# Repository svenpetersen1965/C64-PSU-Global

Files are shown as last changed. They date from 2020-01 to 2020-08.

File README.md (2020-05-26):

# C64-PSU-Global
A replacement PSU for the Commodore C64, which works with 230V/115V.

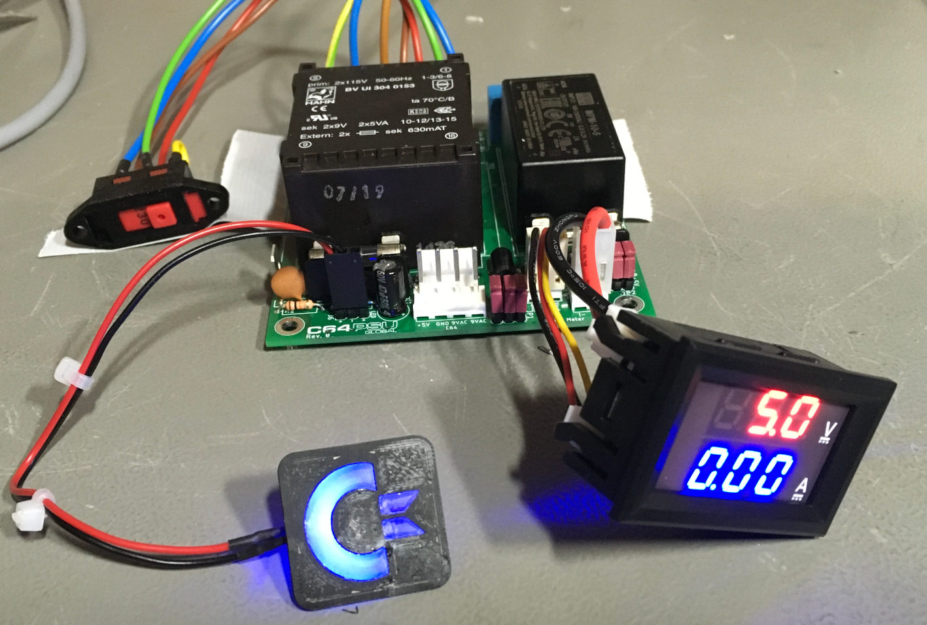
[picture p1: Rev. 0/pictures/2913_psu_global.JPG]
C64 PSU Global (PCB only)
 
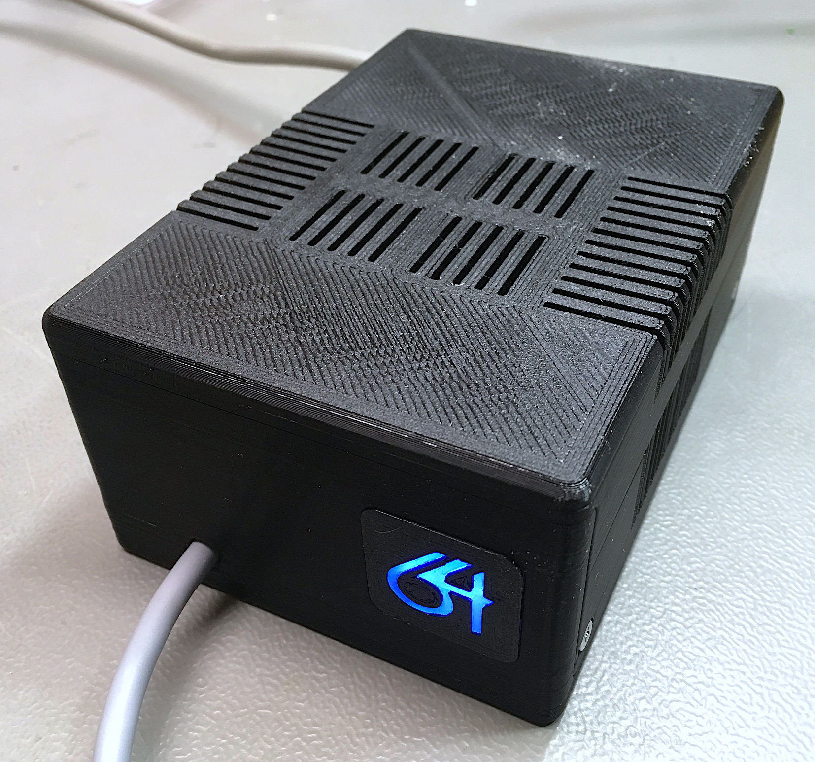
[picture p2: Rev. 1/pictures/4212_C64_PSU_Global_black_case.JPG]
C64 PSU Global (PCB only)


For using this PSU, a suitable enclosure is required. It must not be connected to 230V while 115V mains is selected.

This PSU is designed for a low price at a decent comfort and for providing a PSU that can be switched between 230V and 115V mains.

The testing of Rev. 0 is still preliminary. The PSU was successfully tested with all ASSYs, that I have (250407, 250425, 250466, 250469). The panel meter current measurement worked, but the reading of all panelmeters was off, because those seem to have a bad quality. In Rev. 1 (yet to be released), the current measurement was dropped. The jumpers for bridging the current measurement should be replaced with short wire bridges in Rev. 0.

The changes in <b>Rev. 1</b> are the dropped current measurement. The freed space was used for wider copper tracks. The complete documentation, test documents are released now. The documentation of Rev. 0 will stay incomplete, most of the Rev. 1 documentation applies to Rev. 0 as well.  

Find some info on the required cable making <a href="http://tech.guitarsite.de/cable_making.html">on my website</a>

# Case
The case is designed. At 24°C room temperature the temperature measured above the transformer reached 44°C while powering an ASSY 250425 C64. This is not critical, since the critical temperature for PLA is 55°C-60°C. In case you need to operate the power supply in higher ambient temperatures, you should consider PETG or ABS for printing or install the PSU in a metal case.

The case was designed to fit the <a href="https://github.com/svenpetersen1965/Illuminated-Commmodore-logo">illuminated Commodore Logo</a> or <a href="https://github.com/svenpetersen1965/Illuminated-64-logo">64 Logo</a> (in my repository).  

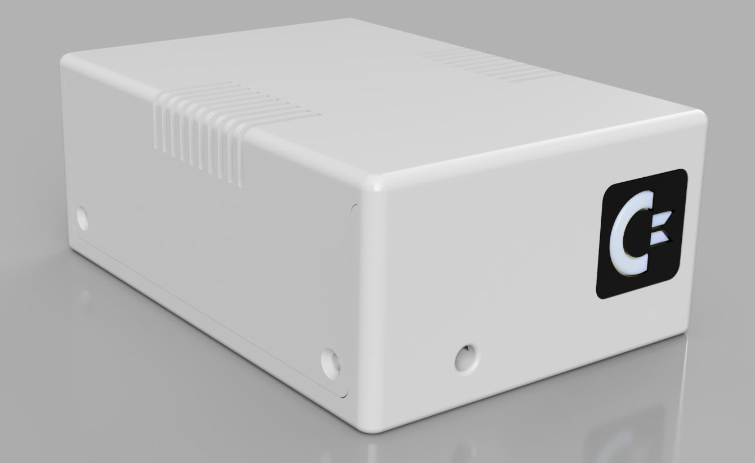
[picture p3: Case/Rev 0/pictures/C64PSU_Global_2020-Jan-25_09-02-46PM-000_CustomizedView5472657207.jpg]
C64 PSU Global case


Since there is a version of the PSU for 230V only and one version that can be switched between 115V and 230V, which requires a mains voltage selector switch, there are two versions for the bottom shell.

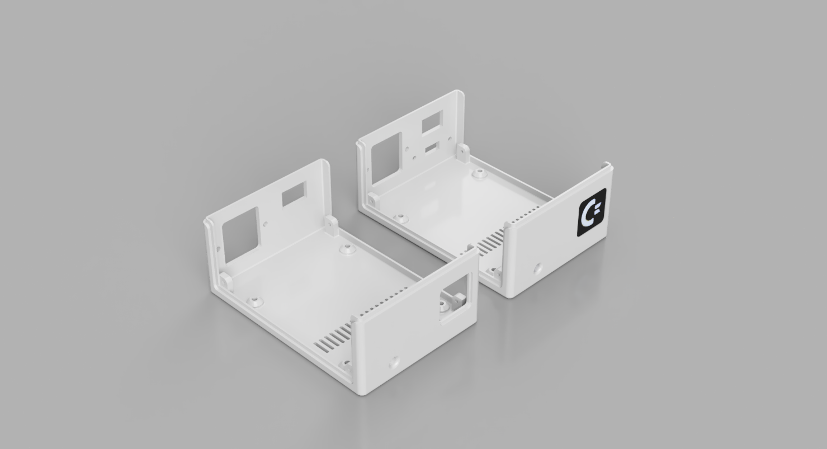
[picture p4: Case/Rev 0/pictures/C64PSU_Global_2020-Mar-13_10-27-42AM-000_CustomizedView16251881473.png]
C64 PSU Global bottom shells


# Prices
I have calculated the prices of May 2020.
Those prices do not include shipping fees and might differ from distributor to distributor. The prices of the items are from reichelt.de and tme.eu.

A 115V/230V type is 40,90€

A 230V only type is 35,11€

This does not incluse the 3D printed case, which might weigh 150g and take 12h to print.

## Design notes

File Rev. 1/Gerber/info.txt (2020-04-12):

      
       Board: C64_PSU_global
       Rev.:  1
  
       Files:
       ======
  
       All Gerber files are generated in extended gerber format (RS274X)
       *.TOP        : Film top copper
       *.BOT        :  -"- bottom copper
       *.STC        :  -"- top soldermask 
       *.STS        :  -"- bottom soldermask
       *.PLC        :  -"- silk screen top
       *.PLS        :  -"- silk screen bottom
       *.DK         : Drills plated Through (Excellon)
       *.NDK        : Drills not plated Through (Excellon)
       *.OUT        : Board outline

       Board Size:
       ===========
       Length     :   90.0 mm
       Width      :   84.0 mm
       Thickness  :   1.6 mm
       Material   :   FR 4
       Copper     :   35 um
       Surface    :   HASL
       
       Remarks:
       ========
       Width >= 8mil
       Distance >= 6mil
       Drill >= 0.6mm

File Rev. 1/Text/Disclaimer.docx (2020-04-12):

Disclaimer

Working with mains voltages can be harmful and cause death. Do not connect this PCB to mains (230VAC) unless you are trained in doing so and know the required safety regulations.

This PSU is a prototype, it is not certified in any way and might only be used as a prototype under laboratory conditions. Usage is at own risk. Do not leave unattended while powered on.

The PSU is designed to be installed in a plastic case. In case a metal case is used, a 3 prong mains connector is required and the case has to be connected to PE in a suitable way.

The documentation is drafted to the best of my knowledge. The creator is not liable for the accuracy and completeness.

Disclaimer.docx 18.02.2020 17:17 Erstellt von Sven Petersen Seite 2 von 2 Dok.-Nr.: 000-8-00-00

Disclaimer.docx 18.02.2020 17:17 Drafted by Sven Petersen Page 1 of 1

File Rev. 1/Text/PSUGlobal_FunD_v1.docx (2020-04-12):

C64 PSU Global Rev. 1

Functional Description

J1 is the mains connector of the board. Up to 240V can be connected. Two types of transformers fit alternatively. TR2 is for 230V only, TR1 can be switched between 230V and 115V. In this case J2 has to be populated. The wiring and connections are shown in the schematics.

M1 and M2 are AC/DC modules, which provide +5V. Both modules can be populated alternatively. The criteria for choosing one of these is availability and price. The function is identical in this case.

F1 is the fuse for the 9VAC. D1 serves as an over-voltage protection.

F2 is the fuse for +5V. C1 and C2 are for smoothing the voltage, D2 is a minimal over-voltage protection. It is equivalent to the TVS diodes, which are sometimes retrofitted in the C64.

JP1 is for connecting an external (and hopefully more precise) over-voltage protection (aka “Saver”). This saver is not yet developed. In case no saver is installed, JP1 should be bridged.

J4 is for connecting a panel volt-meter.

J6 is for connecting a power LED. The value of R1 is calculated for installing a blue LED. For a red or green LED, 330R or 390R are recommended. The illuminated logo already has limiting resistors on board. In case this logo is used as a power indicator, R1 needs to be 0Ω or can be bridged with a piece of wire.

PSUGlobal_FunD_v1.docx 18.02.2020 17:22 Drafted by Sven Petersen Page 2 of 2 Doc.-No.: 133-6-02-01

PSUGlobal_FunD_v1.docx 18.02.2020 17:22 Drafted by Sven Petersen Page 1 of 1 Doc.-No.: 133-6-02-00

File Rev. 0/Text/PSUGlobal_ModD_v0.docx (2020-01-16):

C64 PSU Global Rev. 0

Module Description

# Introduction

The C64 PSU Global is a replacement power supply for the Commodore C64, which is suitable to power the Commodore computer from 115V and 230V.

There are two options for transformers for the 9VAC, one is capable of being switch between 115V and 230V.

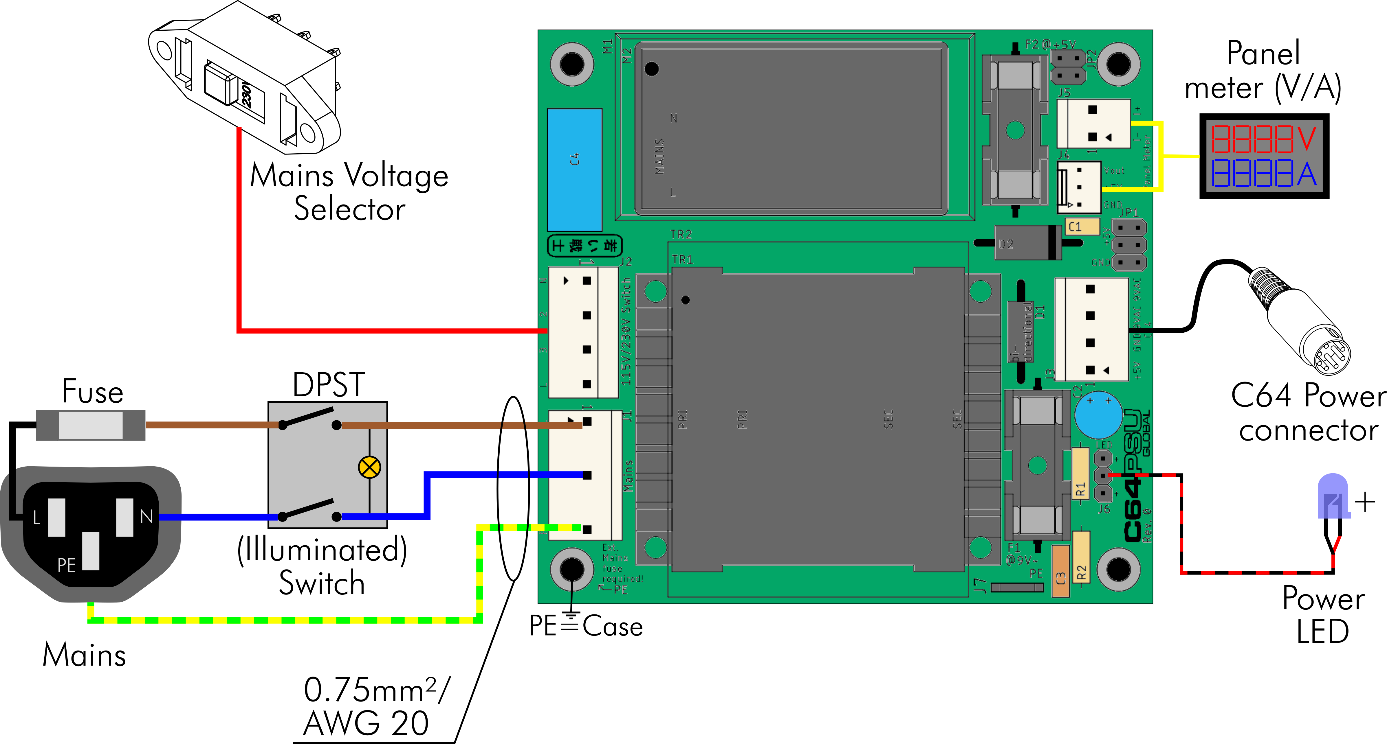
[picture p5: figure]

Figure 1: Block diagram

The 5VDC are generated by an AC/DC converter. There are two options that can be placed on the PCB, both have a wide range input (85VAC-264VAC) and are suitable for both main voltages without switching. The technical data of the power supply vary, depending on the chosen options:

Option | Type | Mains | Output
Transformer TR1 | Hahn BV UI 304 0153 | 115VAC/230VAC | 9VAC/1.1A
Transformer TR2 | BREVE TUFVASSONS TEZ10/D230/9V | 230VAC | 9VAC/1.1A
AC/DC M1 | RECOM RAC10-05SK/277 | 85VAC-305VAC | 5VDC/2A
AC/DC M2 | Mean Well MPM-10-5 | 80VAC-264VAC | 5VDC/2A

The mains voltage selector switch is only required for the option Transformer TR1. A fuse for the mains is external and mandatory. It is recommended to use a combination of mains with an integrated fuse and maybe a switch. The switch should switch off both, the hot and the neutral mains. In Figure 1, an illuminated mains switch is shown. Its lamp is located at the switched side.

A power LED can be connected. At least one signal should allow the use to notice, whether the PSU is switched on or off, the Power LED or the illuminated mains switch.

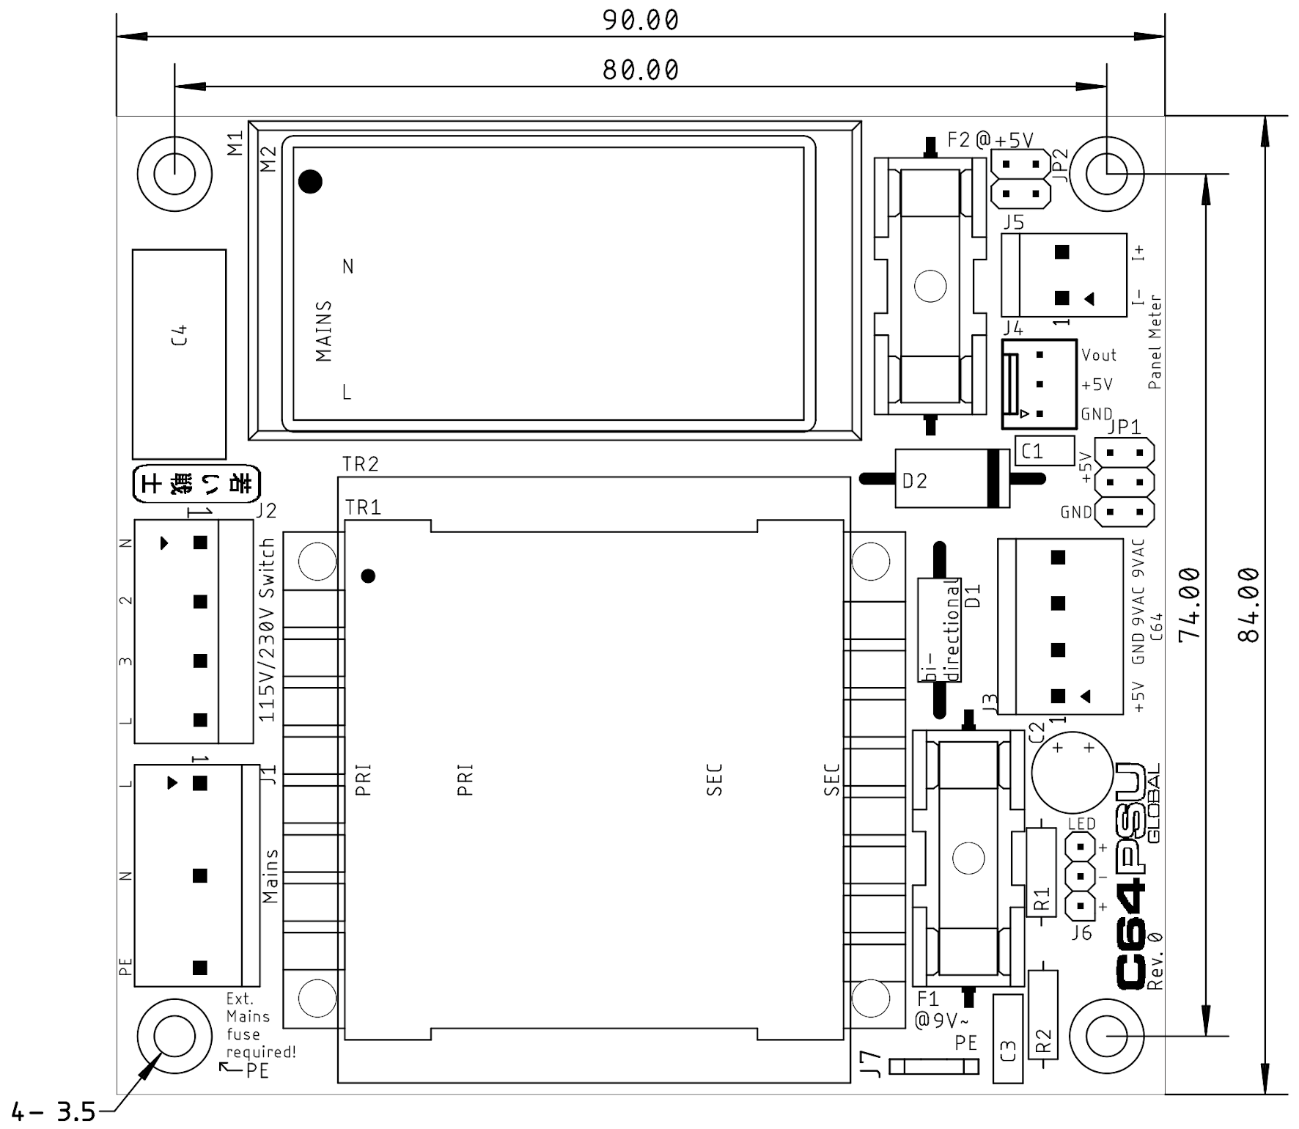
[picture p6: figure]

Figure 2: Dimensions

A panel meter can be connected. The common panel meter measures the current in the negative (ground) lead. The panel meters might be very inaccurate and the current and voltage should be adjusted with a load resistor and a multimeter. Sometimes, it is not even possible to adjust the current properly, so the panel meter is not really recommended. In case the panel meter is not installed, JP2 has to be bridged with jumpers.

A not yet developed over voltage protector (aka C64 saver) can be connected to JP1. In case this is not installed, JP1 has to be bridged with jumpers.

An R/C combination (R2/C3) between GND and PE serves for creating System Ground, which is tied to protective earth (PE). Some further power supplies for the monitor or the S-Video/HDMI converters might inject (a weak) mains voltage into the system. This happens due to a capacitive coupling to mains within those PSUs and could be felt when touching the C64 ports.

# Connectors

## J1 – Mains connectors

- Molex KK 396 Header, Vertical, Friction Lock, 5 Circuits, Tin (Sn) Plating (Pin 2 and pin 4 removed): P/N 0026604050
- KK 3.96mm Crimp Terminal Housing, Friction Ramp, 5 Circuits, Natural: P/N 09503051
- KK 396 Crimp Terminal 2478, 18-24 AWG, Bag, Brass Tin (Sn): P/N 08500106.

Pin | Signal
1 | L (hot)
3 | N (neutral)
5 | PE (protective earth)

## J2 – Mains Voltage Selector

This is an option and only required, if the TR1 (the 115V/230V type) is used.

- Molex 5.08mm Pitch SPOX Wire-to-Board Header, Vertical, with Friction Lock, 4 Circuits, P/N 10321041
- Molex 5.08mm Pitch SPOX Crimp Terminal Housing, 4 Circuits, P/N 10013046
- Molex SPOX Crimp Terminal, 18-24 AWG, Brass, P/N 08701031

As a switch, the type Bulgin T22205B436B is suggested.

## J3 – C64 Power Connector

- Molex KK 396 Header, Vertical, Friction Lock, 4 Circuits, Tin (Sn) Plating: P/N 0026604040
- KK 3.96mm Crimp Terminal Housing, Friction Ramp, 4 Circuits, Natural: P/N 09503041
- KK 396 Crimp Terminal 2478, 18-24 AWG, Bag, Brass Tin (Sn): P/N 08500106.

Pin | Signal
1 | +5V
2 | GND
3 | 9VAC2
4 | 9VAC1

## J4, J5 – Panel Meter

#### J5 – Current path

- Molex KK 396 Header, Vertical, Friction Lock, 2 Circuits, Tin (Sn) Plating: P/N 0026604020
- KK 3.96mm Crimp Terminal Housing, Friction Ramp, 2 Circuits, Natural: P/N 09503021
- KK 396 Crimp Terminal 2478, 18-24 AWG, Bag, Brass Tin (Sn): P/N 08500106.

Pin | Signal
1 | GND PSU (I-)
2 | GND OUT (I+)

### J4 – Voltage connection

- Molex KK 254 Wire-to-Board Header, Vertical, with Friction Lock, 3 Circuits, Tin (Sn) Plating: P/N 22272031
- KK 254 Crimp Housing, 3 Circuits, Natural: P/N 22-01-3037
- KK 254 Crimp Terminal, 22-30 AWG, Bag, Hot Tin (Sn) Dip Plating: P/N 08500114

Pin | Signal
1 | GND
2 | +5V (supply)
3 | +5V (measurement)

## Power LED – J6

- Pin header, 1x3 circuits, 2.54mm (0.1”) pitch
- Crimp housing: Dupont crimp housing
- Dupont crimp terminals

It is possible to use a widely available (Ebay, AliExpress etc.) Dupont cable, which can be cut and soldered to the LED.

Pin | Signal
1 | LED +
2 | LED -
3 | LED +

## J7 – PE Connection

The PE connection to the chassis is accomplished via the mounting hole marked with “← PE”. This is directly connected to the mains connector J1, Pin 5. In case other metal parts have to be grounded, a 6.3 x 0.8 FastOn (spade) connector can be installed in J7.

# Jumpers

## JP1 – Over-Voltage Protection

In case an over-voltage protection is not installed, the pin header JP1 should be bridged. The jumpers should be rated 1A or more.

Signal | Pin | Pin | Signal
Input 5V | 1 | 2 | Output 5V
Input 5V | 3 | 4 | Output 5V
GND | 5 | 6 | GND

## JP2 – Current Path of the Panel Meter

The panel meter measures the current between GND and the negative output lead of J3 (power output). In case the panel meter is not connected, JP3 has to be bridged, otherwise the GND will be open and the 5V are not supplied to the C64.

Signal | Pin | Pin | Signal
GND | 1 | 2 | GNDOUT (J3)
GND | 3 | 4 | GNDOUT (J3)

The jumpers should be rated 1A or more.

# Wiring

This device is connected to mains. Mains voltage is potentially lethal. High currents, that can occur in this device can cause fire hazards. Do not carry out this work, if you are not trained!

Up to four sorts of crimp contacts are required for installing this device:

- FastOn Flat connectors 6.3 x 0.8 (isolated, red) for mains connector/switch
- Molex SPOX/KK 3.96 (J1, J3, J5)
- Molex SPOX/5.08 (J2, option)
- Molex KK2.54 (option)
- Dupont 2.54mm

The crimp tool for the flat connector (FastOn) are cheap. A tool capable of isolated crimps is required. While crimping is the suggested method, the mains connector/fuse/switch can be soldered (do not forget the shrinkable sleeve) as well.

A crimp tool for the other types of connector is the Engineer PA-20. A cheaper, but less good tool is the IWISS IWS-2820M.

The mains should be wired with 0.75mm²/AWG20 cables.

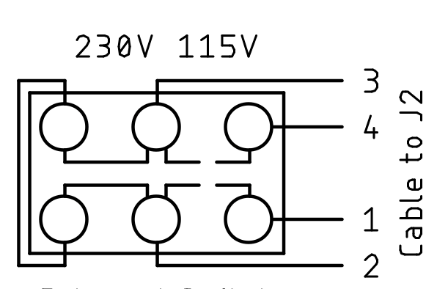
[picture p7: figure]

Figure 3: Wiring of the mains voltage selector switch

The Mains Voltage Selector is optional and has to be wired like shown in Figure 3. The wiring should be checked with a multimeter before the PSU Global is powered up.

Position | Connected | Open
230V | Pin 2 – 3 | Pin 4 – 3, Pin 1 – 2, Pin 1 – 4
115V | Pin 3 – 4, Pin 2 – 1 | Pin 2 – 3, Pin 1 – 4

Table 1: Mains Voltage Selector checks

The installation of the PSU in a metal enclosure requires connection to PE of all metal parts of this enclosure. These connections need to be proved (at least with a multimeter) after finishing the assembly. One mounting hole of the PCB is connected to the PE of the installation. This is marked “← PE”. Chopper disks are recommended to attain a good connection.

In case, the power cables should stay connected to this PSU, strain reliefs are required. An alternative way is a DIN-jack on the back panel of the power supply and extra cables to have as few cables in the installation as possible.

C64 Power Jack | Pin | Voltage
| 1 | -
| 2 | GND
| 3 | -
| 4 | -
| 5 | +5V
| 6 | 9VAC(1)
| 7 | 9VAC(2)

Table 2: Power jack of the C64

Table 2 shows the power jack of the C64. The view is on the particular contact side. This is identical with the view on the solder side of the respective DIN plugs. The cables soldered to the din plugs should be 0.5mm²/AWG21. It is possible to use 0.75mm²/AWG20 wires, but this might require to clip off some of the wire strands, since the solder cups of the DIN plugs are usually not capable of accepting a wire of this diameter.

After finishing the wiring, it is required to test the complete device. Swapping the voltages by confusing the pins or the wiring will usually damage the connected devices. The +5V should measure between +4.9V and +5.2V. The 9VAC are not regulated and might be quite a bit higher without load. 11VAC is still an acceptable reading.

PSUGlobal_ModD_v0.docx 16.01.2020 11:47 Drafted by Sven Petersen Page 2 of 2 Doc.-No.: 133-6-01-00

PSUGlobal_ModD_v0.docx 16.01.2020 11:47 Drafted by Sven Petersen Page 1 of 1 Doc.-No.: 000-6-00-00

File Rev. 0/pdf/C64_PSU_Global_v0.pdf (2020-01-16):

# Project Documentation

## C64 PSU global

## Project number: 133

## Revision: 0

## Date: 15.08.2019

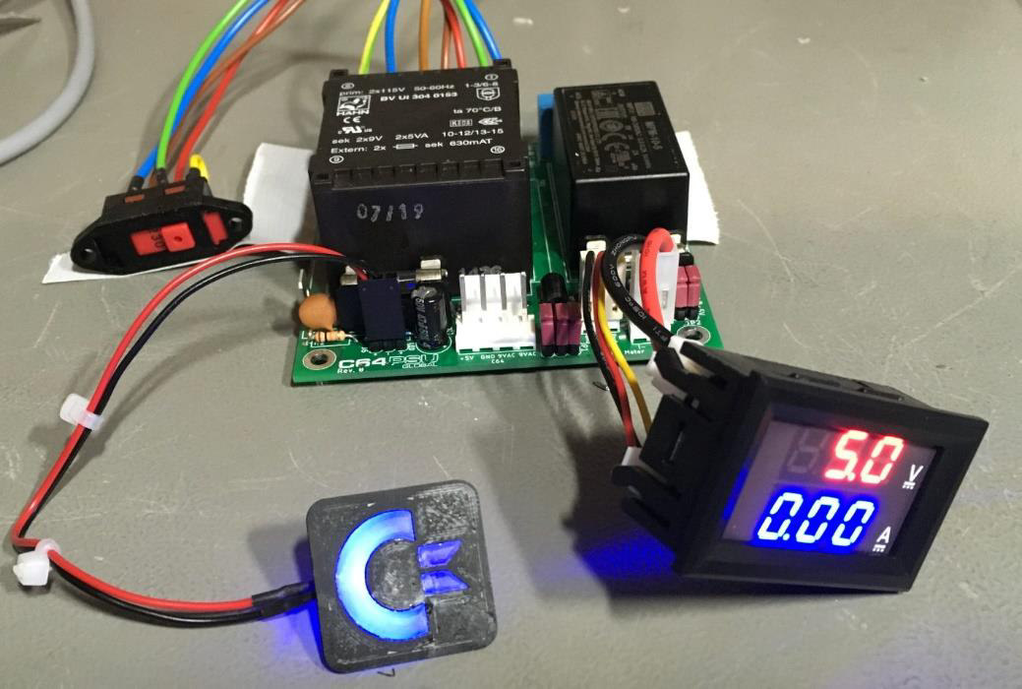
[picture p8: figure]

Disclaimer.docx | 16.01.2020 11:17
Drafted by Sven Petersen | Page 1 of 1

### Disclaimer

Working with mains voltages can be harmful and cause death. Do not connect this PCB to mains (230VAC) unless you are trained in doing so and know the required safety regulations.

This PSU is a prototype, it is not certified in any way and might only be used as a prototype under laboratory conditions. Usage is at own risk.

The PSU is designed to be installed in a plastic case. In case a metal case is used, a 3 prong mains connector is required and the case has to be connected to PE in a suitable way.

The documentation is drafted to the best of my knowledge. The creator is not liable for the accuracy and completeness.

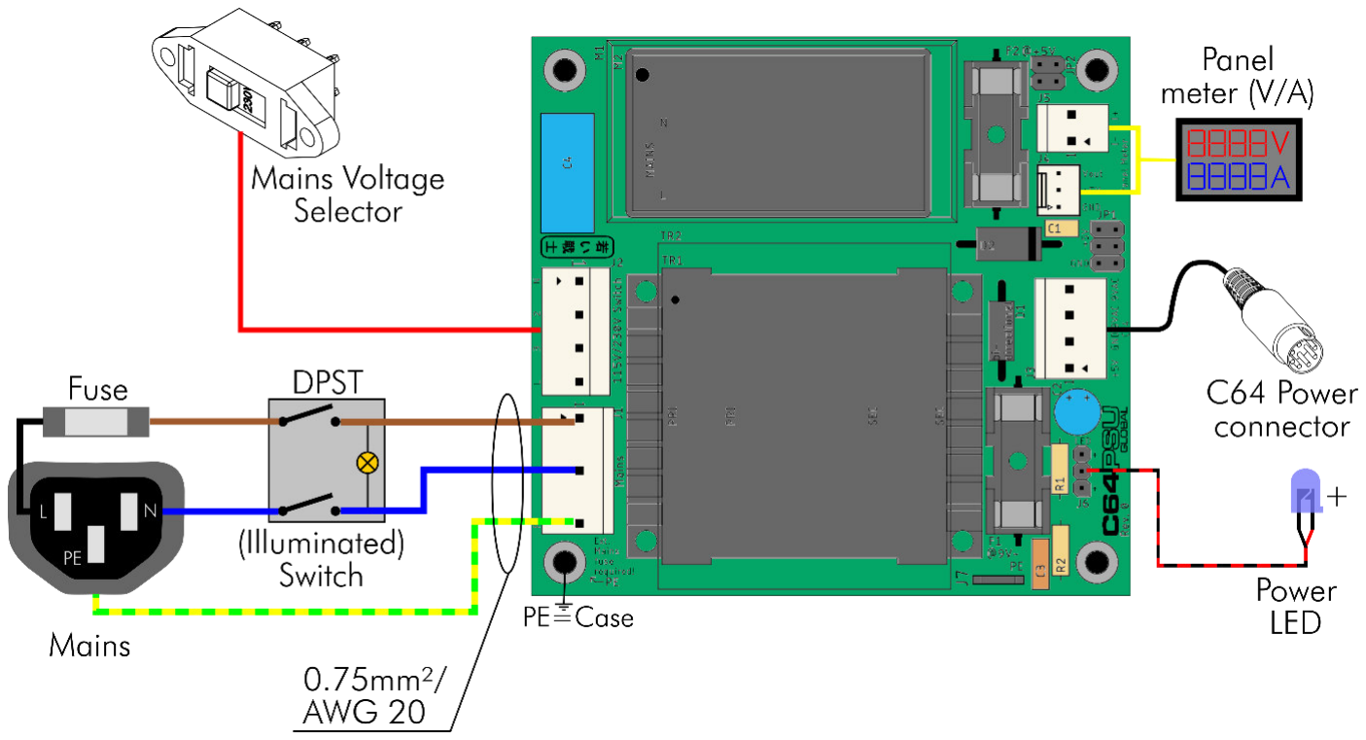
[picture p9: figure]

PSUGlobal_ModD_v0.docx | | 16.01.2020 11:47
Drafted by Sven Petersen | Page 1 of 6 | Doc.-No.: 133-6-01-00

### C64 PSU Global Rev. 0

### Module Description

## Introduction

The C64 PSU Global is a replacement power supply for the Commodore C64, which is suitable to power the Commodore computer from 115V and 230V.

There are two options for transformers for the 9VAC, one is capable of being switch between 115V and 230V.

Figure 1: Block diagram

The 5VDC are generated by an AC/DC converter. There are two options that can be placed on the PCB, both have a wide range input (85VAC-264VAC) and are suitable for both main voltages without switching. The technical data of the power supply vary, depending on the chosen options:

Option | Type | Mains | Output
Transformer TR1 | Hahn BV UI 304 0153 | 115VAC/230VAC | 9VAC/1.1A
Transformer TR2 | BREVE TUFVASSONS TEZ10/D230/9V | 230VAC | 9VAC/1.1A
AC/DC M1 | RECOM RAC10-05SK/277 | 85VAC-305VAC | 5VDC/2A
AC/DC M2 | Mean Well MPM-10-5 | 80VAC-264VAC | 5VDC/2A

The mains voltage selector switch is only required for the option Transformer TR1. A fuse for the mains is external and mandatory. It is recommended to use a combination of mains with an integrated fuse and maybe a switch. The switch should switch off both, the hot and the neutral mains. In Figure 1, an illuminated mains switch is shown. Its lamp is located at the switched side.

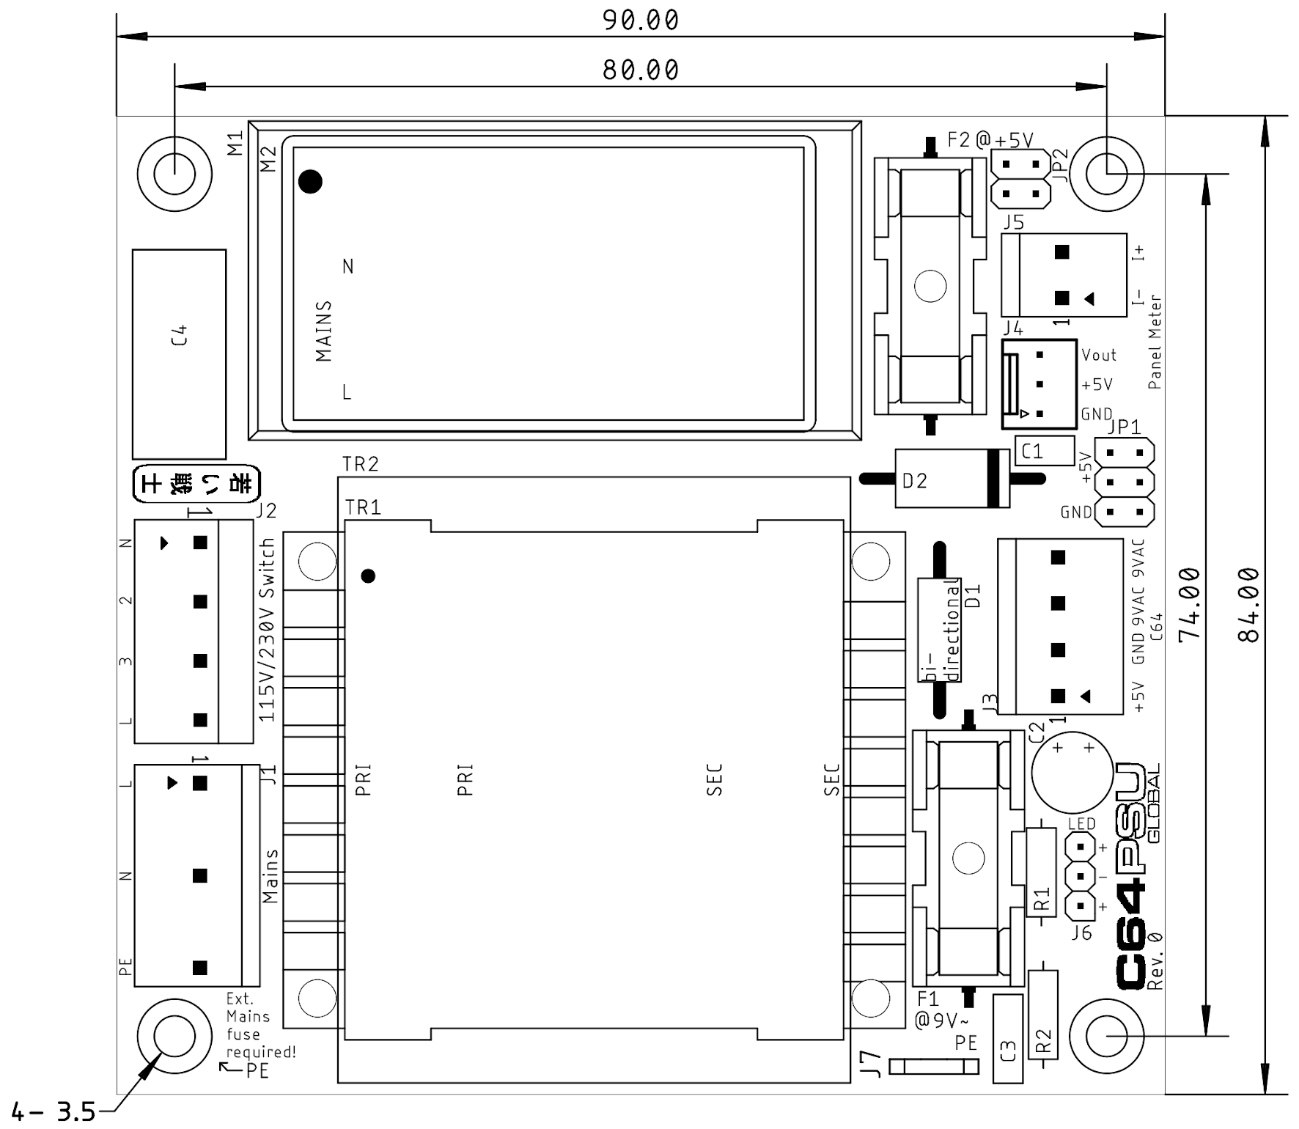
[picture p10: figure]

PSUGlobal_ModD_v0.docx | | 16.01.2020 11:47
Drafted by Sven Petersen | Page 2 of 6 | Doc.-No.: 133-6-01-00

A power LED can be connected. At least one signal should allow the use to notice, whether the PSU is switched on or off, the Power LED or the illuminated mains switch.

Figure 2: Dimensions

A panel meter can be connected. The common panel meter measures the current in the negative (ground) lead. The panel meters might be very inaccurate and the current and voltage should be adjusted with a load resistor and a multimeter. Sometimes, it is not even possible to adjust the current properly, so the panel meter is not really recommended. In case the panel meter is not installed, JP2 has to be bridged with jumpers.

A not yet developed over voltage protector (aka C64 saver) can be connected to JP1. In case this is not installed, JP1 has to be bridged with jumpers.

An R/C combination (R2/C3) between GND and PE serves for creating System Ground, which is tied to protective earth (PE). Some further power supplies for the monitor or the S-Video/HDMI converters might inject (a weak) mains voltage into the system. This happens due to a capacitive coupling to mains within those PSUs and could be felt when touching the C64 ports.

PSUGlobal_ModD_v0.docx | | 16.01.2020 11:47
Drafted by Sven Petersen | Page 3 of 6 | Doc.-No.: 133-6-01-00

## Connectors

### J1 – Mains connectors

- Molex KK 396 Header, Vertical, Friction Lock, 5 Circuits, Tin (Sn) Plating (Pin 2 and pin 4 removed): P/N 0026604050
- KK 3.96mm Crimp Terminal Housing, Friction Ramp, 5 Circuits, Natural: P/N 09503051
- KK 396 Crimp Terminal 2478, 18-24 AWG, Bag, Brass Tin (Sn): P/N 08500106.

Pin Signal
1 L (hot)
3 N (neutral)
5 PE (protective earth)

### J2 – Mains Voltage Selector

This is an option and only required, if the TR1 (the 115V/230V type) is used.

- Molex 5.08mm Pitch SPOX Wire-to-Board Header, Vertical, with Friction Lock, 4 Circuits, P/N 10321041
- Molex 5.08mm Pitch SPOX Crimp Terminal Housing, 4 Circuits, P/N 10013046
- Molex SPOX Crimp Terminal, 18-24 AWG, Brass, P/N 08701031

As a switch, the type Bulgin T22205B436B is suggested.

### J3 – C64 Power Connector

- Molex KK 396 Header, Vertical, Friction Lock, 4 Circuits, Tin (Sn) Plating:
P/N 0026604040
- KK 3.96mm Crimp Terminal Housing, Friction Ramp, 4 Circuits, Natural: P/N 09503041
- KK 396 Crimp Terminal 2478, 18-24 AWG, Bag, Brass Tin (Sn): P/N 08500106.

Pin Signal
1 +5V
2 GND
3 9VAC2
4 9VAC1

### J4, J5 – Panel Meter

J5 – Current path
- Molex KK 396 Header, Vertical, Friction Lock, 2 Circuits, Tin (Sn) Plating:
P/N 0026604020
- KK 3.96mm Crimp Terminal Housing, Friction Ramp, 2 Circuits, Natural: P/N 09503021
- KK 396 Crimp Terminal 2478, 18-24 AWG, Bag, Brass Tin (Sn): P/N 08500106.

Pin Signal
1 GND PSU (I-)
2 GND OUT (I+)
J4 – Voltage connection
- Molex KK 254 Wire-to-Board Header, Vertical, with Friction Lock, 3 Circuits, Tin (Sn) Plating: P/N 22272031
- KK 254 Crimp Housing, 3 Circuits, Natural: P/N 22-01-3037

PSUGlobal_ModD_v0.docx | | 16.01.2020 11:47
Drafted by Sven Petersen | Page 4 of 6 | Doc.-No.: 133-6-01-00
- KK 254 Crimp Terminal, 22-30 AWG, Bag, Hot Tin (Sn) Dip Plating: P/N 08500114

Pin Signal
1 GND
2 +5V (supply)
3 +5V (measurement)

### Power LED – J6 - Pin header, 1x3 circuits, 2.54mm (0.1”) pitch

- Crimp housing: Dupont crimp housing
- Dupont crimp terminals

It is possible to use a widely available (Ebay, AliExpress etc.) Dupont cable, which can be cut and soldered to the LED.

Pin Signal
1 LED +
2 LED -
3 LED +

### J7 – PE Connection

The PE connection to the chassis is accomplished via the mounting hole marked with “← PE”. This is directly connected to the mains connector J1, Pin 5. In case other metal parts have to be grounded, a 6.3 x 0.8 FastOn (spade) connector can be installed in J7.

## Jumpers

### JP1 – Over-Voltage Protection

In case an over-voltage protection is not installed, the pin header JP1 should be bridged. The jumpers should be rated 1A or more.

Signal Pin | Pin Signal
Input 5V | 1 | 2 | Output 5V
Input 5V | 3 | 4 | Output 5V
GND | 5 | 6 | GND

### JP2 – Current Path of the Panel Meter

The panel meter measures the current between GND and the negative output lead of J3 (power output). In case the panel meter is not connected, JP3 has to be bridged, otherwise the GND will be open and the 5V are not supplied to the C64.

Signal Pin | Pin Signal
GND | 1 | 2 | GNDOUT (J3)
GND | 3 | 4 | GNDOUT (J3)

The jumpers should be rated 1A or more.

## Wiring

This device is connected to mains. Mains voltage is potentially lethal. High currents, that can occur in this device can cause fire hazards. Do not carry out this work, if you are not trained!


PSUGlobal_ModD_v0.docx | | 16.01.2020 11:47
Drafted by Sven Petersen | Page 5 of 6 | Doc.-No.: 133-6-01-00

Up to four sorts of crimp contacts are required for installing this device:

- FastOn Flat connectors 6.3 x 0.8 (isolated, red) for mains connector/switch
- Molex SPOX/KK 3.96 (J1, J3, J5)
- Molex SPOX/5.08 (J2, option)
- Molex KK2.54 (option)
- Dupont 2.54mm

The crimp tool for the flat connector (FastOn) are cheap. A tool capable of isolated crimps is required. While crimping is the suggested method, the mains connector/fuse/switch can be soldered (do not forget the shrinkable sleeve) as well.

A crimp tool for the other types of connector is the Engineer PA-20. A cheaper, but less good tool is the IWISS IWS-2820M.

The mains should be wired with 0.75mm²/AWG20 cables.

Figure 3: Wiring of the mains voltage selector switch

The Mains Voltage Selector is optional and has to be wired like shown in Figure 3. The wiring should be checked with a multimeter before the PSU Global is powered up.

Position | Connected | Open
230V | Pin 2 – 3 | Pin 4 – 3, Pin 1 – 2, Pin 1 – 4
115V | Pin 3 – 4, Pin 2 – 1 | Pin 2 – 3, Pin 1 – 4
Table 1: Mains Voltage Selector checks

The installation of the PSU in a metal enclosure requires connection to PE of all metal parts of this enclosure. These connections need to be proved (at least with a multimeter) after finishing the assembly. One mounting hole of the PCB is connected to the PE of the installation. This is marked
“← PE”. Chopper disks are recommended to attain a good connection.

In case, the power cables should stay connected to this PSU, strain reliefs are required. An alternative way is a DIN-jack on the back panel of the power supply and extra cables to have as few cables in the installation as possible.

C64 Power Jack | Pin | Voltage
1 -
2 GND
3 -
4 -
5 +5V
6 9VAC(1)
7 9VAC(2)
Table 2: Power jack of the C64

PSUGlobal_ModD_v0.docx | | 16.01.2020 11:47
Drafted by Sven Petersen | Page 6 of 6 | Doc.-No.: 133-6-01-00

Table 2 shows the power jack of the C64. The view is on the particular contact side. This is identical with the view on the solder side of the respective DIN plugs. The cables soldered to the din plugs should be 0.5mm²/AWG21. It is possible to use 0.75mm²/AWG20 wires, but this might require to clip off some of the wire strands, since the solder cups of the DIN plugs are usually not capable of accepting a wire of this diameter.

After finishing the wiring, it is required to test the complete device. Swapping the voltages by confusing the pins or the wiring will usually damage the connected devices. The +5V should measure between +4.9V and +5.2V. The 9VAC are not regulated and might be quite a bit higher without load. 11VAC is still an acceptable reading.

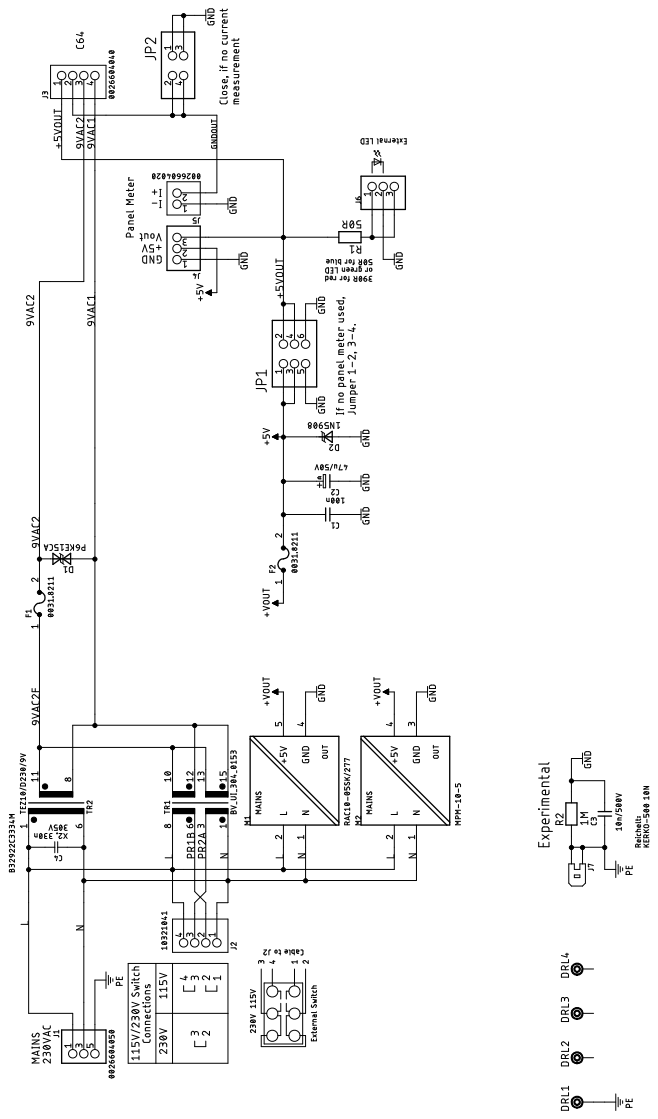
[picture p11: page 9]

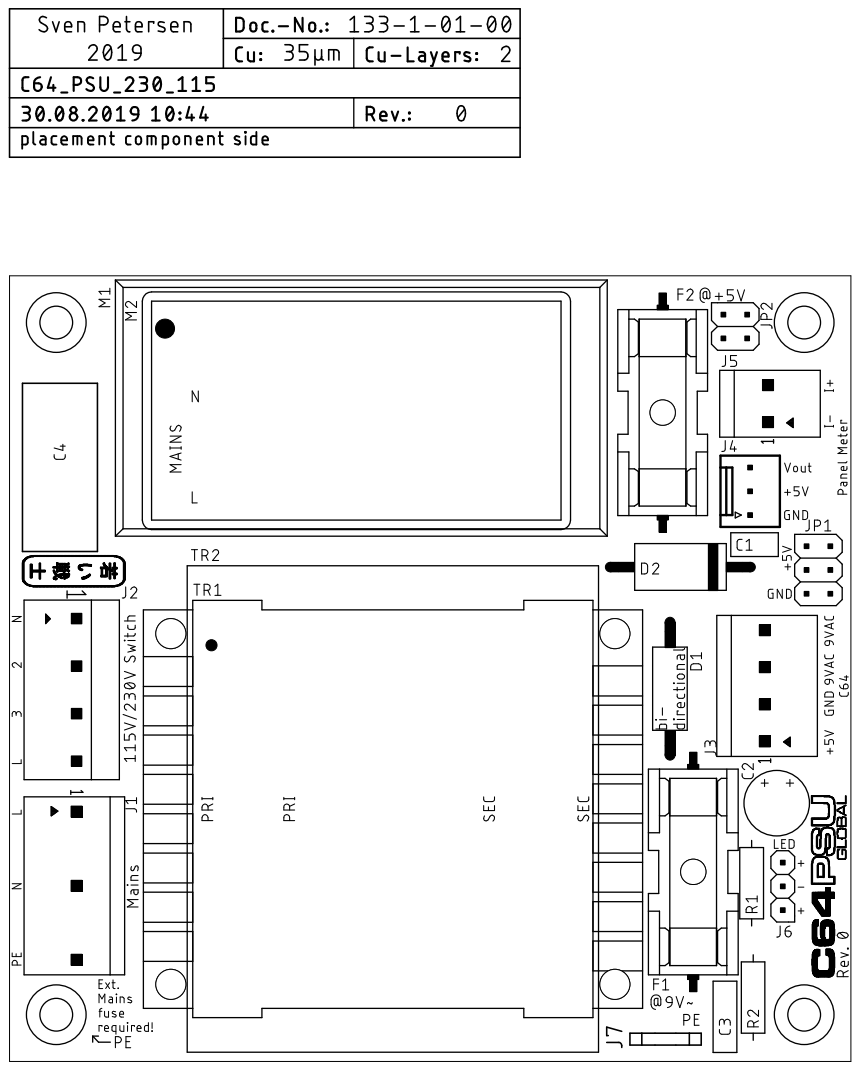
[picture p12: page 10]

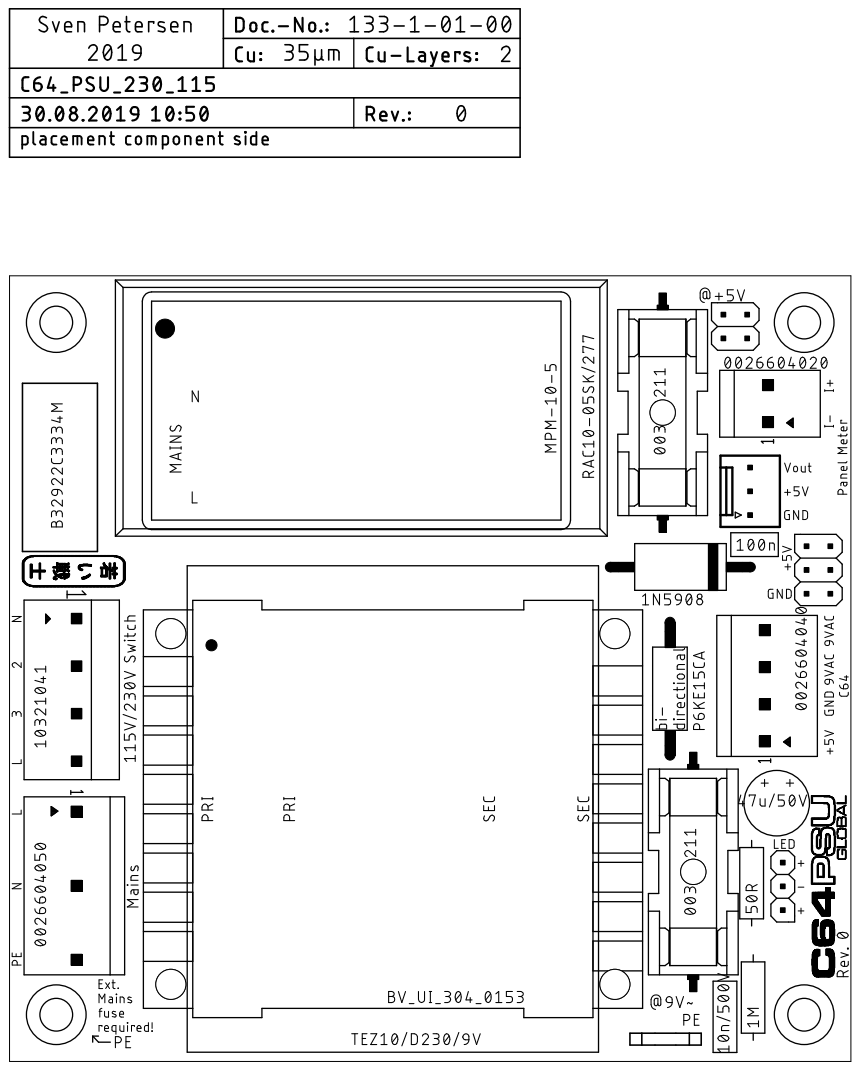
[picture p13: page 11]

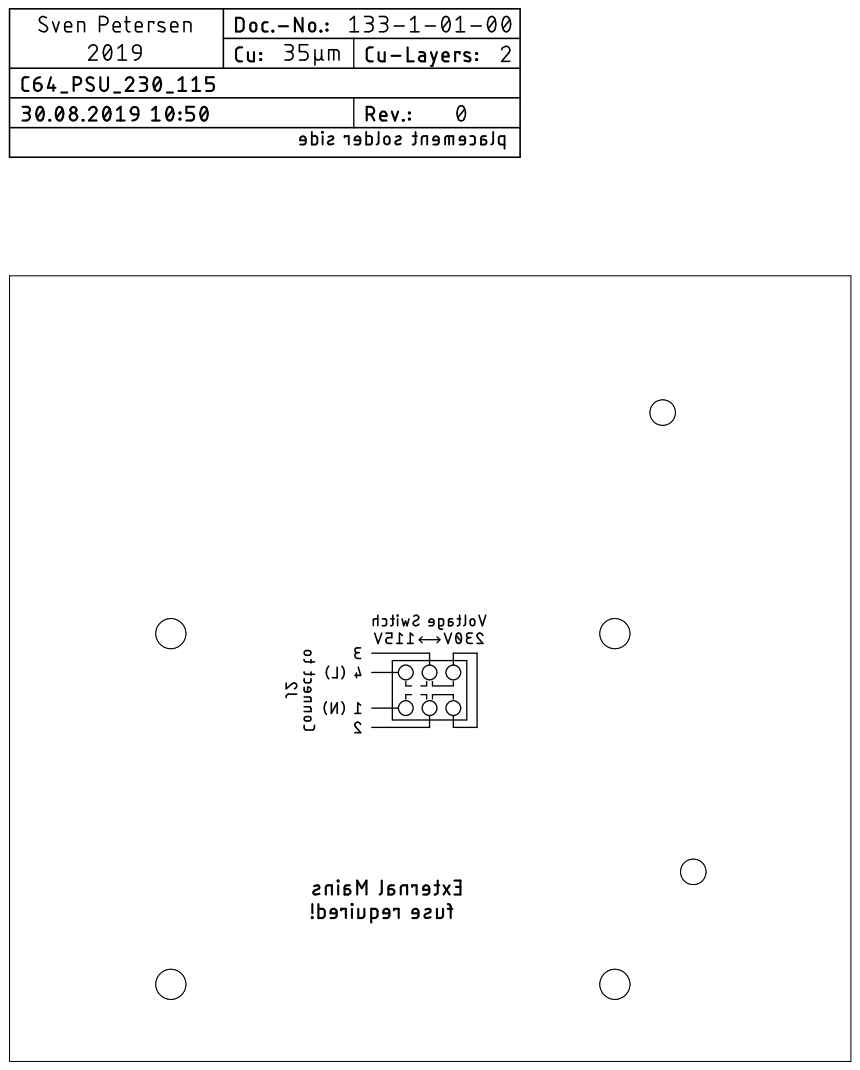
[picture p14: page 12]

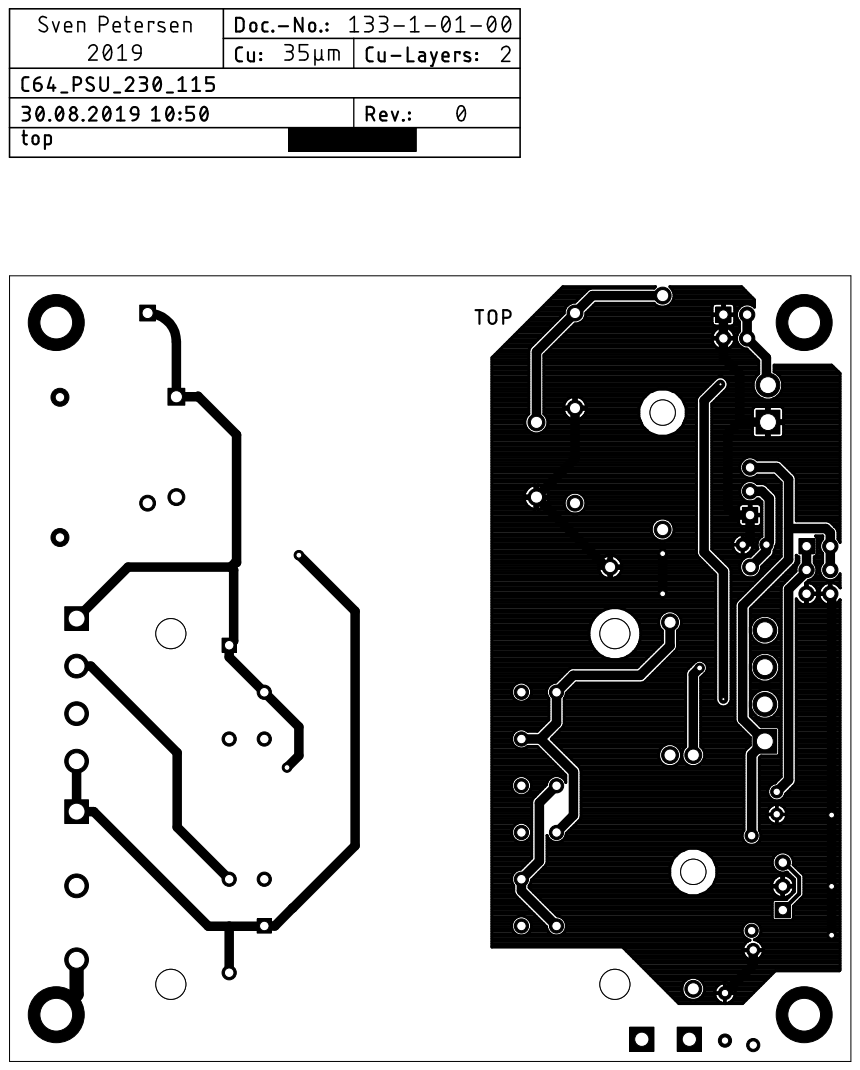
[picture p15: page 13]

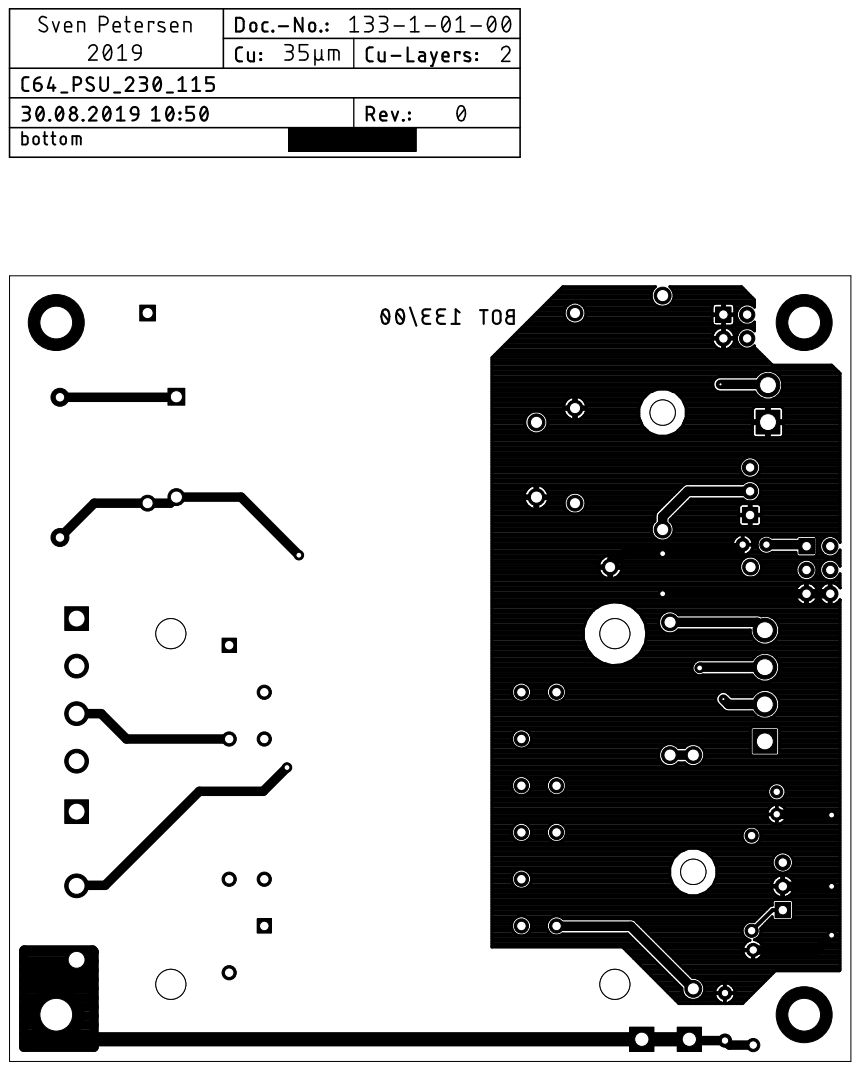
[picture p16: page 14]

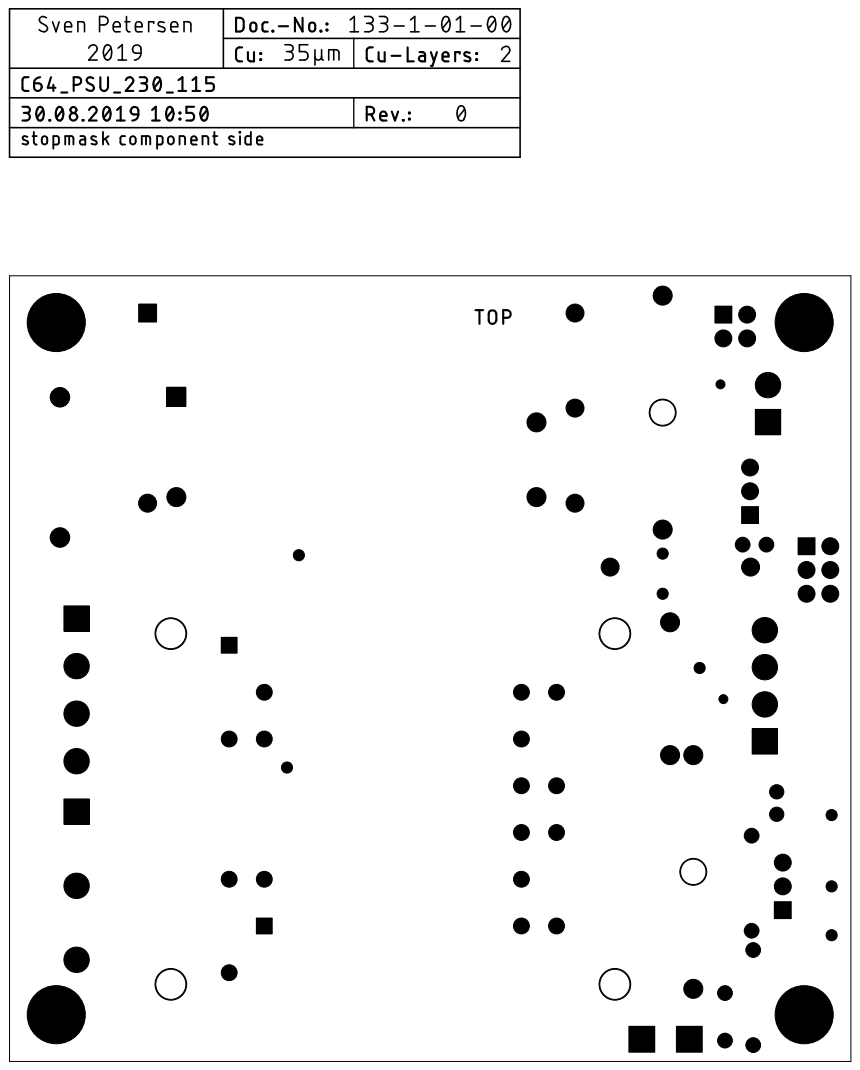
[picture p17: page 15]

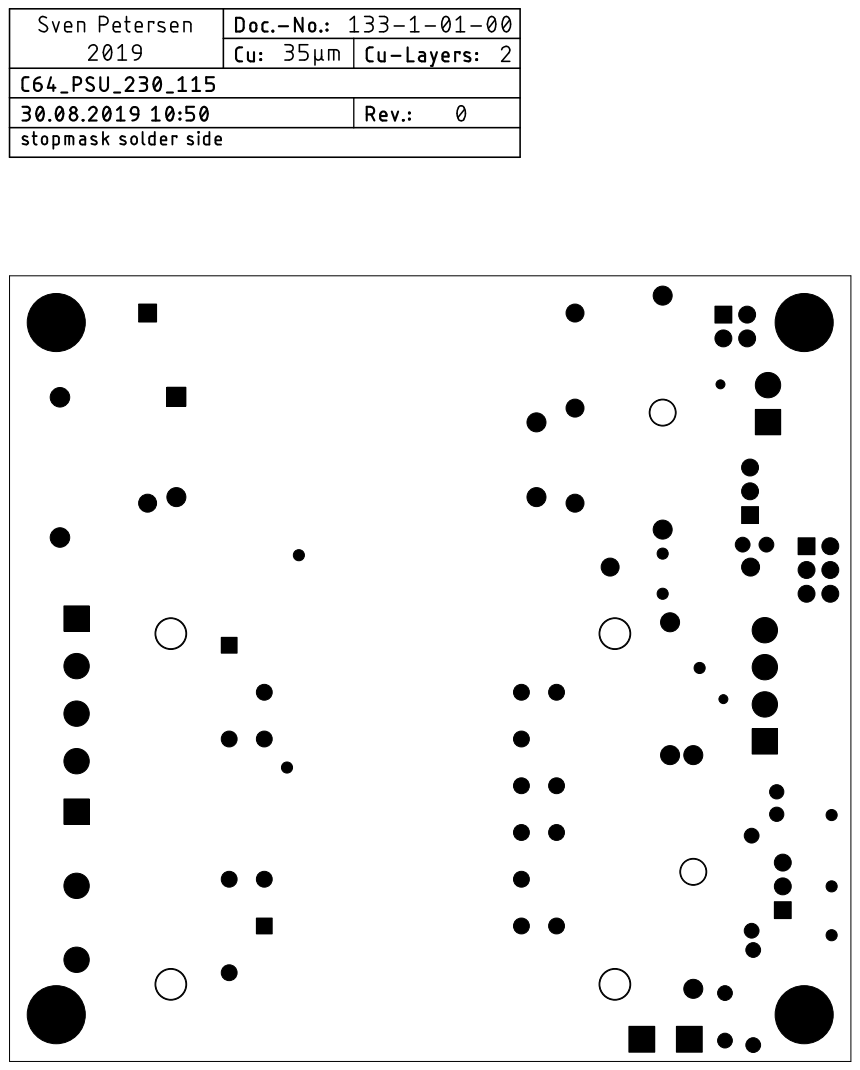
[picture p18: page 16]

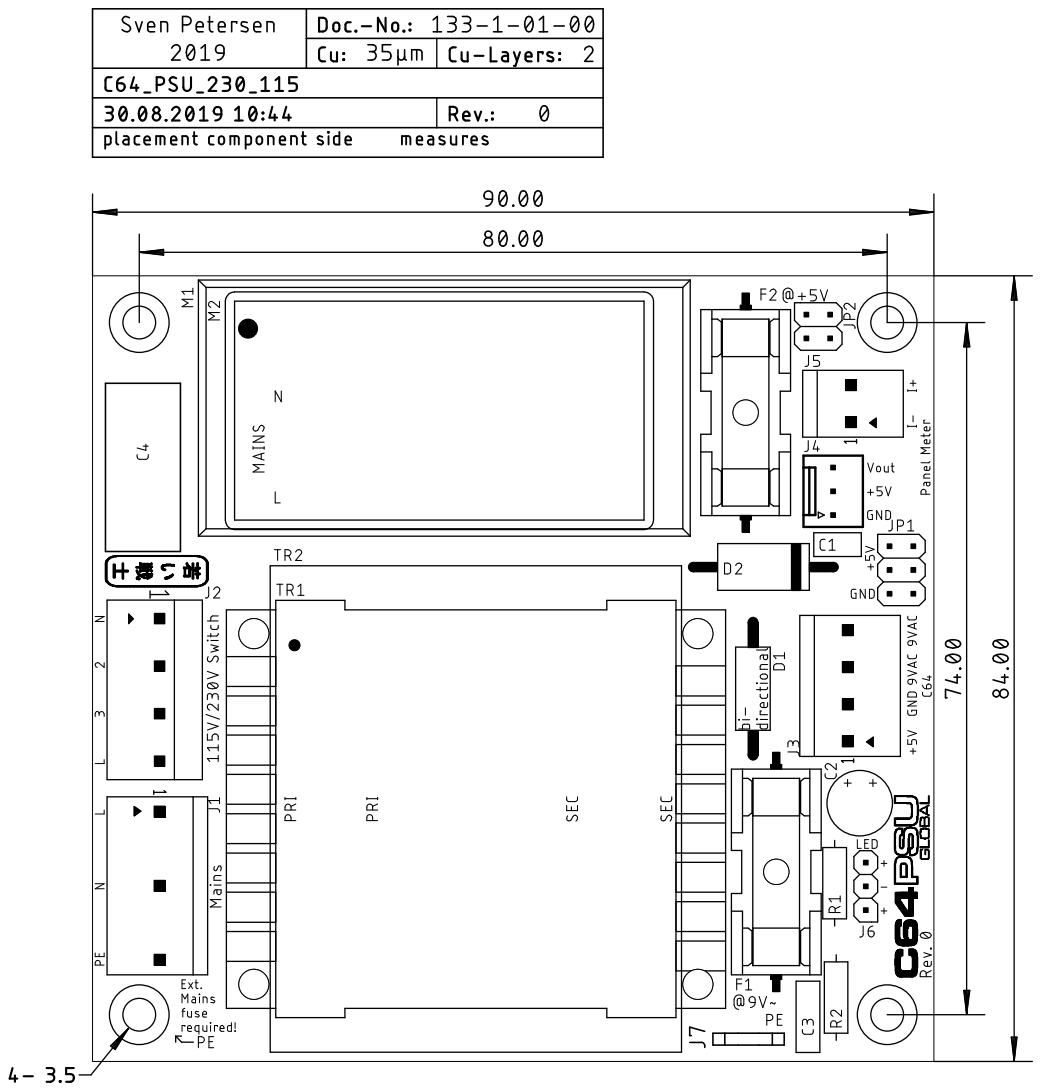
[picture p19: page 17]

PSUGlobal_FunD_v0.docx | | 16.01.2020 11:56
Drafted by Sven Petersen | Page 1 of 1 | Doc.-No.: 133-6-02-00

### C64 PSU Global Rev. 0

### Functional Description

J1 is the mains connector of the board. Up to 240V can be connected. Two types of transformers fit alternatively. TR2 is for 230V only, TR1 can be switched between 230V and 115V. In this case J2 has to be populated. The wiring and connections are shown in the schematics.

M1 and M2 are AC/DC modules, which provide +5V. Both modules can be populated alternatively. The criteria for choosing one of these is availability and price. The function is identical in this case.

F1 is the fuse for the 9VAC. D1 serves as an over-voltage protection.

F2 is the fuse for +5V. C1 and C2 are for smoothing the voltage, D2 is a minimal over-voltage protection. It is equivalent to the TVS diodes, which are sometimes retrofitted in the C64.

JP1 is for connecting an external (and hopefully more precise) over-voltage protection (aka “Saver”). This saver is not yet developed. In case no saver is installed, JP1 should be bridged.

J4 and J5 are for connecting a panel meter. In case this is not connected, the output ground (GNDOUT) has to be bridged on JP2.

J6 is for connecting a power LED. The value of R1 is calculated for installing a blue LED. For a red or green LED, 330R or 390R are recommended.

PSUGlobal_Test_v0.docx | | 16.01.2020 11:56
Drafted by Sven Petersen | Page 1 of 1 | Doc.-No.: 133-6-03-00

### C64 PSU Global Rev. 0

### Testing

The testing is still preliminary.

The testing was performed with a prototype configured for the 230V/115V option at 230V mains voltage. The output voltage was observed while being connected to load resistors for one hour. A C64 was powered (ASSY250469).

A test with 115V was not yet performed.

The 230V only transformer (TR2) fits the footprint on the PCB. This option has not been built, yet and not been tested.

Pos. | Qty Value | Footprint | Ref.-No. | Comment
1 | 1 133-2-01-00 | 2 Layer | PCB Rev. 0 | 2 layer, Cu 35µ, HASL, 90.0 x 84.0, 1.6mm FR4
2 | 1 22-27-2031 | 6410-3P | J4 | optional (for panel meter): Molex 6410/22-27-2031 (KK, 2.54mm, 3p), e.g. Reichelt: MOLEX 22272031, tme.eu: MX-6410- 03A
3 | 1 22-01-3037 | | (J4) | crimp housing, optional (for panel meter), Molex. E.g.
| | | | Reichelt: MOLEX 22013037, tme.eu: MX-22-01-3037
4 | 3 08-50-0114 | | (J4) | crimp terminal, optional (for panel meter), Molex. E.g.
| | | | Reichelt: MOLEX 8500114, tme.eu: MX-0850-0114
5 | 1 6.3 x 0.8 | FLA6,3 | J7 | optional PE connector, PCB mount spade connectors
6 | 1 1x3p, 2.54mm | 1X03 | J6 | standard pin header, 2.54mm pitch
7 | 1 dupont housing, 3p | | (J6) | ebay, AliExpress or other
8 | 2 dupont terminals, female | | (J6) | ebay, AliExpress or other
9 | 1 LED, blue | | (J6) | Power LED, blue (R1 is calculated for blue)
10 | 1 2x2p, 2.54mm | 2X02 | JP2 | standard pin header, 2.54mm pitch
11 | 1 2x3p, 2.54mm | 2X03 | JP1 | standard pin header, 2.54mm pitch
12 | 5 jumper, 2.54mm | | (JP1), (JP2) | standard jumper (rated 1A or more). E.G. Reichelt: JUMPER
| | | | 2,54 SW, tme.eu: 63429-202LF
13 | 1 26604020 | SPOX_3.96_2P | J5 | optional (for panel meter): Molex SPOX, e.G. Reichelt: MOLEX 26604020, tme.eu: MX-26-60-4020
14 | 1 09503021 | | (J5) | crimp housing, optional (for panel meter): Molex. E.g. Reichelt: MOLEX 9503021, tme.eu: MX-2139-2A
15 | 2 08500106 | | (J5) | crimp terminal, optional (for panel meter), Molex. E.g. Reichelt: MOLEX 08500106, tme.eu: MX-2478-1-P913L (= 10 pack)
16 | 1 26604040 | SPOX_3.96_4P | J3 | Molex SPOX, e.G. Reichelt: MOLEX 26604040, tme.eu: MX-26- 60-4040
17 | 1 09503041 | | (J3) | crimp housing: Molex. E.g. Reichelt: MOLEX 9503041, tme.eu: MX-2139-4A
18 | 4 08500106 | | (J3) | crimp terminal, Molex. E.g. Reichelt: MOLEX 08500106, tme.eu: MX-2478-1-P913L (= 10 pack)

## C64 PSU GLOBAL Rev. 0 Bill of Material Rev. 0.0

C64_PSU_Global_BoM_v0_0.xlsx
Drafted by Sven Petersen | Page 1 of 3

16.01.2020 11:58
Doc.No.: 133-5-01-00.0

Pos. | Qty Value | Footprint | Ref.-No. | Comment

## C64 PSU GLOBAL Rev. 0 Bill of Material Rev. 0.0

19 | 1 26604050 | SPOX_3.96_5P3 | J1 | Modification: Remove Pin 2 and Pin 4. Molex SPOX, e.G. Reichelt: MOLEX 26604050, tme.eu: MX-26-60-4050
20 | 1 09503051 | | (J1) | crimp housing: Molex. E.g. Reichelt: MOLEX 9503051, tme.eu: MX-2139-5A
21 | 3 08500106 | | (J1) | crimp terminal, Molex. E.g. Reichelt: MOLEX 08500106, tme.eu: MX-2478-1-P913L (= 10 pack)
22 | 2 0031.8211 | 318211 | F1, F2 | Schurter fuse holder (5x20mm). E.g. Reichelt: PL OGN-25, tme.eu:
| | | | 0031.8211
23 | 1 5x20mm, 1.6A | | (F1) | Fuse for 9VAC
24 | 1 5x20mm, 2A | | (F2) | Fuse for 5VDC
25 | 1 100n | C-2,5 | C1 | Ceramic Cap, 50V, pitch 2.5mm
26 | 1 10321041 | SPOX_5.08_4P | J2 | MOLEX, option: 115V/230V switch, tme.eu: MX-5281-04A
27 | 1 10013046 | | (J2) | MOLEX, option: 115V/230V switch., tme.eu: MX-5197-04, Farnell: 2612656 , Mouser: 538-10-01-3046 , Digikey: WM9124-ND
28 | 4 08701031 | | (J2) | Molex Crimp terminal, option 115V/230V, Farnell: 2060658, rs- online.com: 670-6265, Mouser 538-08-70-1031-CT, Digikey: WM18820CT-ND
29 | 1 T22205B436B | | (J2) | Bulgin, option 115/230V (switch), tme.eu: AE-T22205B
30 | 1 10n/500V | C-5 | C3 | Ceramic Cap, 500V, pitch 5mm, Reichelt: KERKO-500
| | | | 10N, tme.eu: CCH-10K (=10 pack)
31 | 1 1M | R-10 | R2 | Resistor, metal film, 5% or better, 0,6W
32 | 1 1N5908 | CB429 | D2 | 5V TVS diode. ST Micro. E.g. Reichelt: 1N 5908, tme.eu:
| | | | 1N5908
33 | 1 47u/50V | C07/2,5 | C2 | el. Cap, 105°C, diameter 7mm, pitch 2.5mm
34 | 1 50R | R-10 | R1 | Resistor, metal film, 5% or better, 0,6W, calculated for blue
| | | | led. For red, green, yellow: 330R
35 | 1 B32922C3334M | C-18X8-RM15 | C4 | X2-capacitor, 330n, 305V, EPCOS. E.g. Reichelt EPCO
| | | | B32922C3334, tme.eu: B32922C3334M

C64_PSU_Global_BoM_v0_0.xlsx
Drafted by Sven Petersen | Page 2 of 3
| | | | 16.01.2020 11:58
| | | | Doc.No.: 133-5-01-00.0

Pos. | Qty Value | Footprint | Ref.-No. | Comment

## C64 PSU GLOBAL Rev. 0 Bill of Material Rev. 0.0

36 | 1 BV UI 304 0153 | UI30 | TR1 | Hahn transformer, option 115V/230V, tme.eu: BVUI3040153
37 | 1 MPM-10-5 | MPM10 | M2 | Mean Well, +5V@10W AC/DC module. tme.eu: MPM-10-
| | | | 5, Digikey: 1866-3459-ND, Farnell: 3002904, Mouser:
| | | | 709-MPM10-5. Alternative for M1.
38 | 1 P6KE15CA | CB417NP | D1 | 15V bi-dir TVS diode, ST Micro, e.G. Reichelt: P6KE 15CA,
| | | | tme.eu: P6KE15CA
39 | 1 RAC10-05SK/277 | RAC10-K/277 | M1 | RECOM, +5V@10W AC/DC module. Tme.eu: RAC10-
| | | | 05SK/277, Digikey: 945-3121-5-ND, Farnell: 2822839,
| | | | Mouser: 919-RAC10-05SK/277. Alternative for M2.
40 | 1 TEZ10/D230/9V | TEZ10 | TR2 | BREVE TUFVASSONS transformer, option 230V only,
| | | | tme.eu: TEZ10/D/9V
41 | 1 6200.2300 | | | Schurter, tme.eu: 6200.2300. Example for main connector with
| | | | fuse.
42 | 1 1835.3118 | | | Marquardt, tme.eu: 1835.3118. Example for an illuminated mains
| | | | switch
43 | 7 2-520184-2 | | | TE connectivity, tme.eu: 2-520184-2 or Reichelt RND 465-
| | | | 00067. Example for 6.3 x 0.8 spade terminals, red, fully isolated.
| | | | Required to connect to teh mains connector and switch.
44 | 1 MAS 70S | | | Hirschmann DIN plug 7pin, 262°. Reichelt: MAS 70S, tme.eu:
| | | | MAS70SGR. Example for C64 power plug
45 1.5m | 4x0.5mm² | Cable for output voltages. 4xAWG21

### 46 wires for mains and the LED

C64_PSU_Global_BoM_v0_0.xlsx
Drafted by Sven Petersen | Page 3 of 3

16.01.2020 11:58
Doc.No.: 133-5-01-00.0

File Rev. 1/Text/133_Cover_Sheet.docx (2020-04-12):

Project Documentation

C64 PSU global

Project number: 133

Revision: 1

Date: 18.02.2020

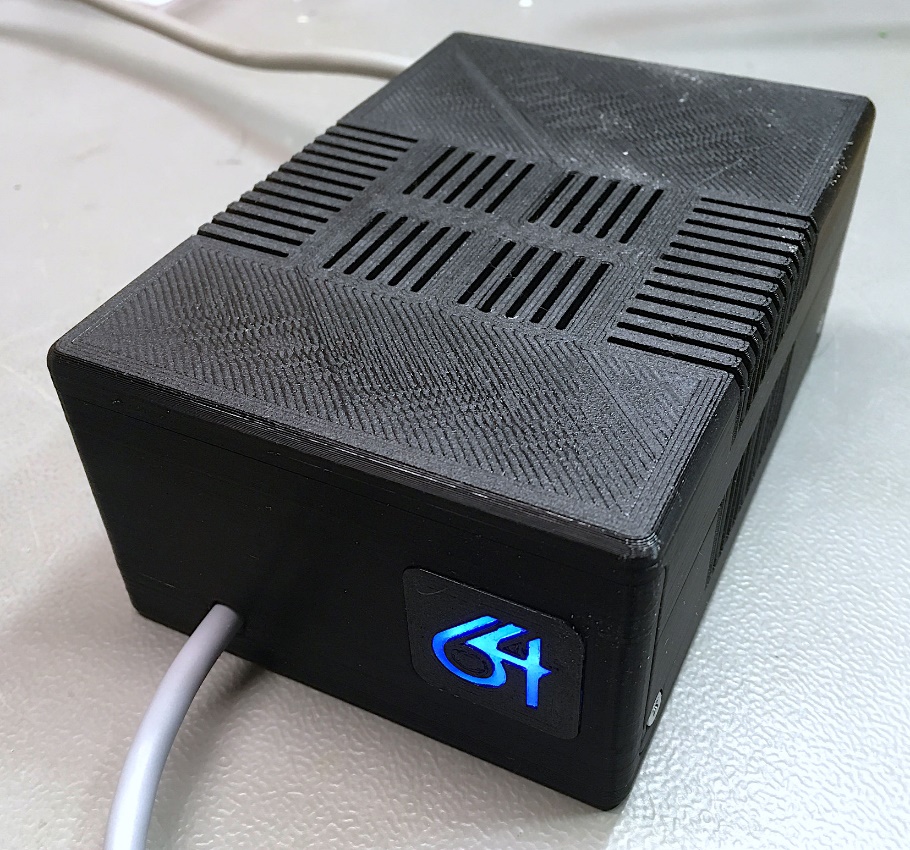
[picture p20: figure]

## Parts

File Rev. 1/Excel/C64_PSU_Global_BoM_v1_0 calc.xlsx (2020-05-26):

C64 PSU GLOBAL Rev. 1
Bill of Material Rev. 1.0
Pos. | Qty | Value | Comment | priece/each | Price total
1 | 1 | 133-2-01-00 | 2 layer, Cu 35µ, HASL, 90.0 x 84.0, 1.6mm FR4 | 1.00 € | 1.00 €
2 | 0 | 22-27-2031 | optional (for panel meter): Molex 6410/22-27-2031 (KK, 2.54mm, 3p), e.g. Reichelt: MOLEX 22272031, tme.eu: MX-6410-03A | 0.00 € | 0.00 €
3 | 0 | 22-01-3037 | crimp housing, optional (for panel meter), Molex. E.g. Reichelt: MOLEX 22013037, tme.eu: MX-22-01-3037 | 0.00 € | 0.00 €
4 | 0 | 08-50-0114 | crimp terminal, optional (for panel meter), Molex. E.g. Reichelt: MOLEX 8500114, tme.eu: MX-0850-0114 | 0.00 € | 0.00 €
5 | 0 | 6.3 x 0.8 | optional PE connector, PCB mount spade connectors | 0.00 € | 0.00 €
6 | 1 | 1x3p, 2.54mm | standard pin header, 2.54mm pitch | 0.08 € | 0.08 €
7 | 1 | dupont housing, 3p | ebay, AliExpress or other | 0.05 € | 0.05 €
8 | 2 | dupont terminals, female | ebay, AliExpress or other | 0.01 € | 0.02 €
9 | 0 | LED, blue | Power LED, blue (R1 is calculated for blue) | 0.28 € | 0.00 €
10 | 0 | 2x2p, 2.54mm | standard pin header, 2.54mm pitch | 0.00 € | 0.00 €
11 | 1 | 2x4p, 2.54mm | standard pin header, 2.54mm pitch | 0.06 € | 0.06 €
12 | 4 | jumper, 2.54mm | standard jumper (rated 1A or more). E.G. Reichelt: JUMPER 2,54 SW, tme.eu: 63429-202LF | 0.02 € | 0.08 €
13 | 0 | 26604020 | optional (for panel meter): Molex SPOX, e.G. Reichelt: MOLEX 26604020, tme.eu: MX-26-60-4020 | 0.00 € | 0.00 €
14 | 0 | 09503021 | crimp housing, optional (for panel meter): Molex. E.g. Reichelt: MOLEX 9503021, tme.eu: MX-2139-2A | 0.00 € | 0.00 €
15 | 0 | 08500106 | crimp terminal, optional (for panel meter), Molex. E.g. Reichelt: MOLEX 08500106, tme.eu: MX-2478-1-P913L (= 10 pack) | 0.00 € | 0.00 €
16 | 1 | 26604040 | Molex SPOX, e.G. Reichelt: MOLEX 26604040, tme.eu: MX-26-60-4040 | 0.26 € | 0.26 €
17 | 1 | 09503041 | crimp housing: Molex. E.g. Reichelt: MOLEX 9503041, tme.eu: MX-2139-4A | 0.14 € | 0.14 €
18 | 4 | 08500106 | crimp terminal, Molex. E.g. Reichelt: MOLEX 08500106, tme.eu: MX-2478-1-P913L (= 10 pack) | 0.10 € | 0.40 €
19 | 1 | 26604050 | Modification: Remove Pin 2 and Pin 4. Molex SPOX, e.G. Reichelt: MOLEX 26604050, tme.eu: MX-26-60-4050 | 0.32 € | 0.32 €
20 | 1 | 09503051 | crimp housing: Molex. E.g. Reichelt: MOLEX 9503051, tme.eu: MX-2139-5A | 0.16 € | 0.16 €
21 | 3 | 08500106 | crimp terminal, Molex. E.g. Reichelt: MOLEX 08500106, tme.eu: MX-2478-1-P913L (= 10 pack) | 0.10 € | 0.30 €
22 | 2 | 0031.8211 | Schurter fuse holder (5x20mm). E.g. Reichelt: PL OGN-25, tme.eu: 0031.8211 | 0.45 € | 0.90 €
23 | 1 | 5x20mm, 1.6A | Fuse for 9VAC | 0.08 € | 0.08 €
24 | 1 | 5x20mm, 2A | Fuse for 5VDC | 0.08 € | 0.08 €
25 | 1 | 100n | Ceramic Cap, 50V, pitch 2.5mm | 0.10 € | 0.10 €
26 | 0 | 10321041 | MOLEX, option: 115V/230V switch, tme.eu: MX-5281-04A | 0.62 € | 0.00 €
27 | 0 | 10013046 | MOLEX, option: 115V/230V switch., tme.eu: MX-5197-04, Farnell: 2612656 , Mouser: 538-10-01-3046 , Digikey: WM9124-ND | 0.62 € | 0.00 €
28 | 0 | 08701031 | Molex Crimp terminal, option 115V/230V, Farnell: 2060658, rs-online.com: 670-6265, Mouser 538-08-70-1031-CT, Digikey: WM18820CT-ND | 0.06 € | 0.00 €
29 | 0 | T22205B436B | Bulgin, option 115/230V (switch), tme.eu: AE-T22205B | 2.40 € | 0.00 €
30 | 1 | 10n/500V | Ceramic Cap, 500V, pitch 5mm, Reichelt: KERKO-500 10N, tme.eu: CCH-10K (=10 pack) | 0.12 € | 0.12 €
31 | 1 | 1M | Resistor, metal film, 5% or better, 0,6W | 0.10 € | 0.10 €
32 | 1 | 1N5908 | 5V TVS diode. ST Micro. E.g. Reichelt: 1N 5908, tme.eu: 1N5908 | 0.36 € | 0.36 €
33 | 1 | 47u/50V | el. Cap, 105°C, diameter 7mm, pitch 2.5mm | 0.11 € | 0.11 €
34 | 1 | 50R | Resistor, metal film, 5% or better, 0,6W, calculated for blue led. For red, green, yellow: 330R. For illuminated logo: 0R! | 0.10 € | 0.10 €
35 | 1 | B32922C3334M | X2-capacitor, 330n, 305V, EPCOS. E.g. Reichelt EPCO B32922C3334, tme.eu: B32922C3334M | 0.29 € | 0.29 €
36 | 0 | BV UI 304 0153 | Hahn transformer, option 115V/230V, tme.eu: BVUI3040153 | 6.43 € | 0.00 €
37 | 1 | MPM-10-5 | Mean Well, +5V@10W AC/DC module. tme.eu: MPM-10-5, Digikey: 1866-3459-ND, Farnell: 3002904, Mouser: 709-MPM10-5. Alternative for M1. | 10.35 € | 10.35 €
38 | 1 | P6KE15CA | 15V bi-dir TVS diode, ST Micro, e.G. Reichelt: P6KE 15CA, tme.eu: P6KE15CA | 0.20 € | 0.20 €
39 | 0 | RAC10-05SK/277 | RECOM, +5V@10W AC/DC module. Tme.eu: RAC10-05SK/277, Digikey: 945-3121-5-ND, Farnell: 2822839, Mouser: 919-RAC10-05SK/277. Alternative for M2. | 11.10 € | 0.00 €
40 | 1 | TEZ10/D230/9V | BREVE TUFVASSONS transformer, option 230V only, tme.eu: TEZ10/D/9V | 4.52 € | 4.52 €
41 | 1 | 6200.2300 | Schurter, tme.eu: 6200.2300. Mains connector with fuse. | 2.36 € | 2.36 €
42 | 1 | 1855.1108 | Marquardt, tme.eu: 1855.1108, Reichelt.de: WIPPE 1855.1108. Illuminated mains switch for the 3D printed case. Non-illuminated switch: Marquardt 1858.1103, Reichelt: WIPPE 1858.1103, tme.eu: 1858.1103 | 4.66 € | 4.66 €
43 | 1 | 2-520184-2 | TE connectivity, tme.eu: 2-520184-2 or Reichelt RND 465-00067. Example for 6.3 x 0.8 spade terminals, red, fully isolated. Required to connect to the mains connector and switch. | 0.30 € | 0.30 €
44 | 1 | MAS 70S | Hirschmann DIN plug 7pin, 262°. Reichelt: MAS 70S, tme.eu: MAS70SGR. Example for C64 power plug | 0.47 € | 0.47 €
45 | 1 | 4x0.5mm² | Cable for output voltages. 4xAWG21 | 1.00 € | 1.00 €
46 | 4 | 4.8 x 0.8, isolated, red, female | Blade receptacle, e.g. tme.eu: BM00148, Reichelt.de: RND 465-00508 | 0.09 € | 0.36 €
47 | 0 | 6.3 x 0.8, isolated, red, female | Blade receptacle, e.g. tme.eu: , Reichelt.de: RND 465-00045 | 1.00 € | 0.00 €
48 | 1 | 0.5A/T | Mains fuse | 0.08 € | 0.08 €
49 | 1 | 3D printed case | ABS |  | 0.00 €
50 | 1 | mains cable, 0.5mm² - 0.75mm² | To be salvaged for the mains cables | 1.00 € | 1.00 €
51 |  | cable 0.5mm², red | for the 230V/115V version |  | 0.00 €
52 |  | cable 0.5mm², green | for the 230V/115V version |  | 0.00 €
53 |  | cable 0.25mm²/AWG24, red |  |  | 0.00 €
54 |  | cable 0.25mm²/AWG24, black |  |  | 0.00 €
55 | 1 | illuminated logo | see text | 2.50 € | 2.50 €
56 | 4 | M3x10 (DIN 7985) | screw | 0.10 € | 0.40 €
57 | 8 | M3, self-locking (DIN 985) | nut | 0.10 € | 0.80 €
58 | 4 | M3x12 (DIN 965) | countersunk screw | 0.10 € | 0.40 €
59 | 2 | C2.9x9.5mm (DIN 7981) | screw for sheet metal or plastic | 0.10 € | 0.20 €
60 | 4 | C2.9x6.5mm (DIN 7982) | countersunk screw for sheet metal or plastic | 0.10 € | 0.40 €
61 |  |  | Total |  | 35.11 €
 |  |  | 115/230V |  | 40.90 €
 |  |  | 230V only |  | 35.11 €

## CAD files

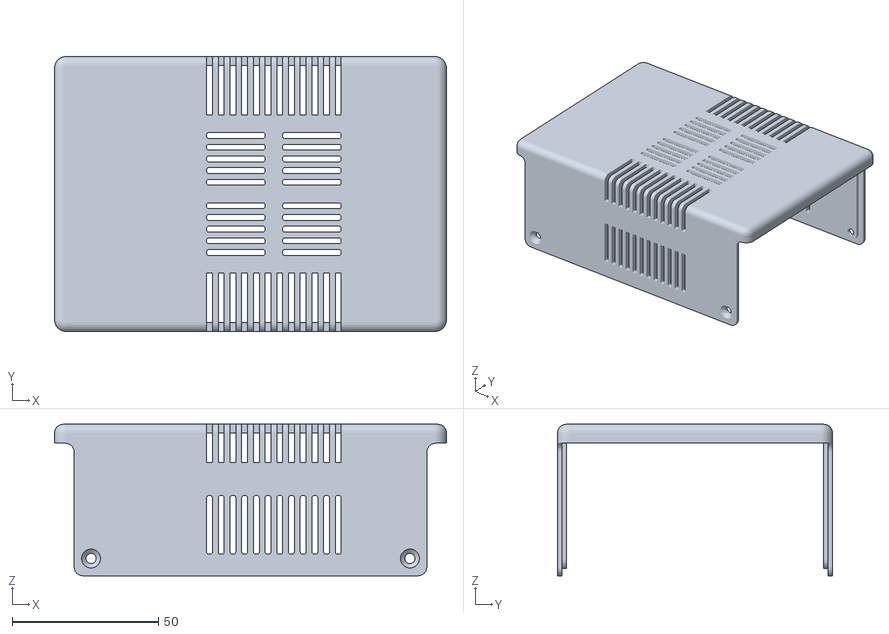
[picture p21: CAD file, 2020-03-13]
Case/Rev 0/stl/psug_top_shell.stl
134.0 x 94.0 x 51.8

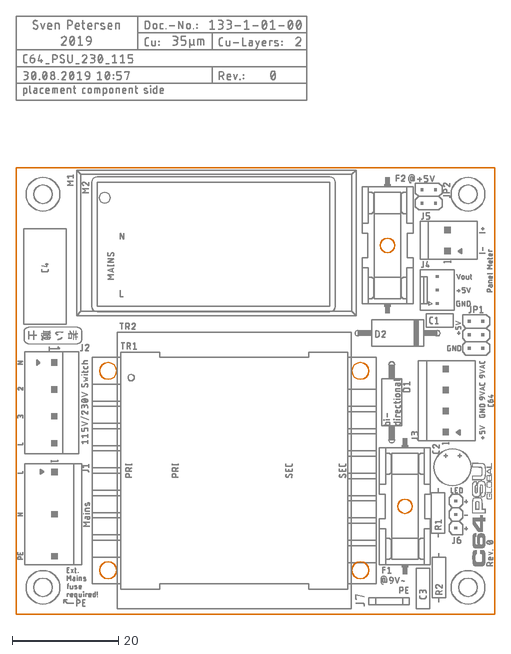
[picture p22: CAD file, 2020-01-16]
Rev. 1/dxf/C64_PSU_230_115.dxf
90.0 x 112.6

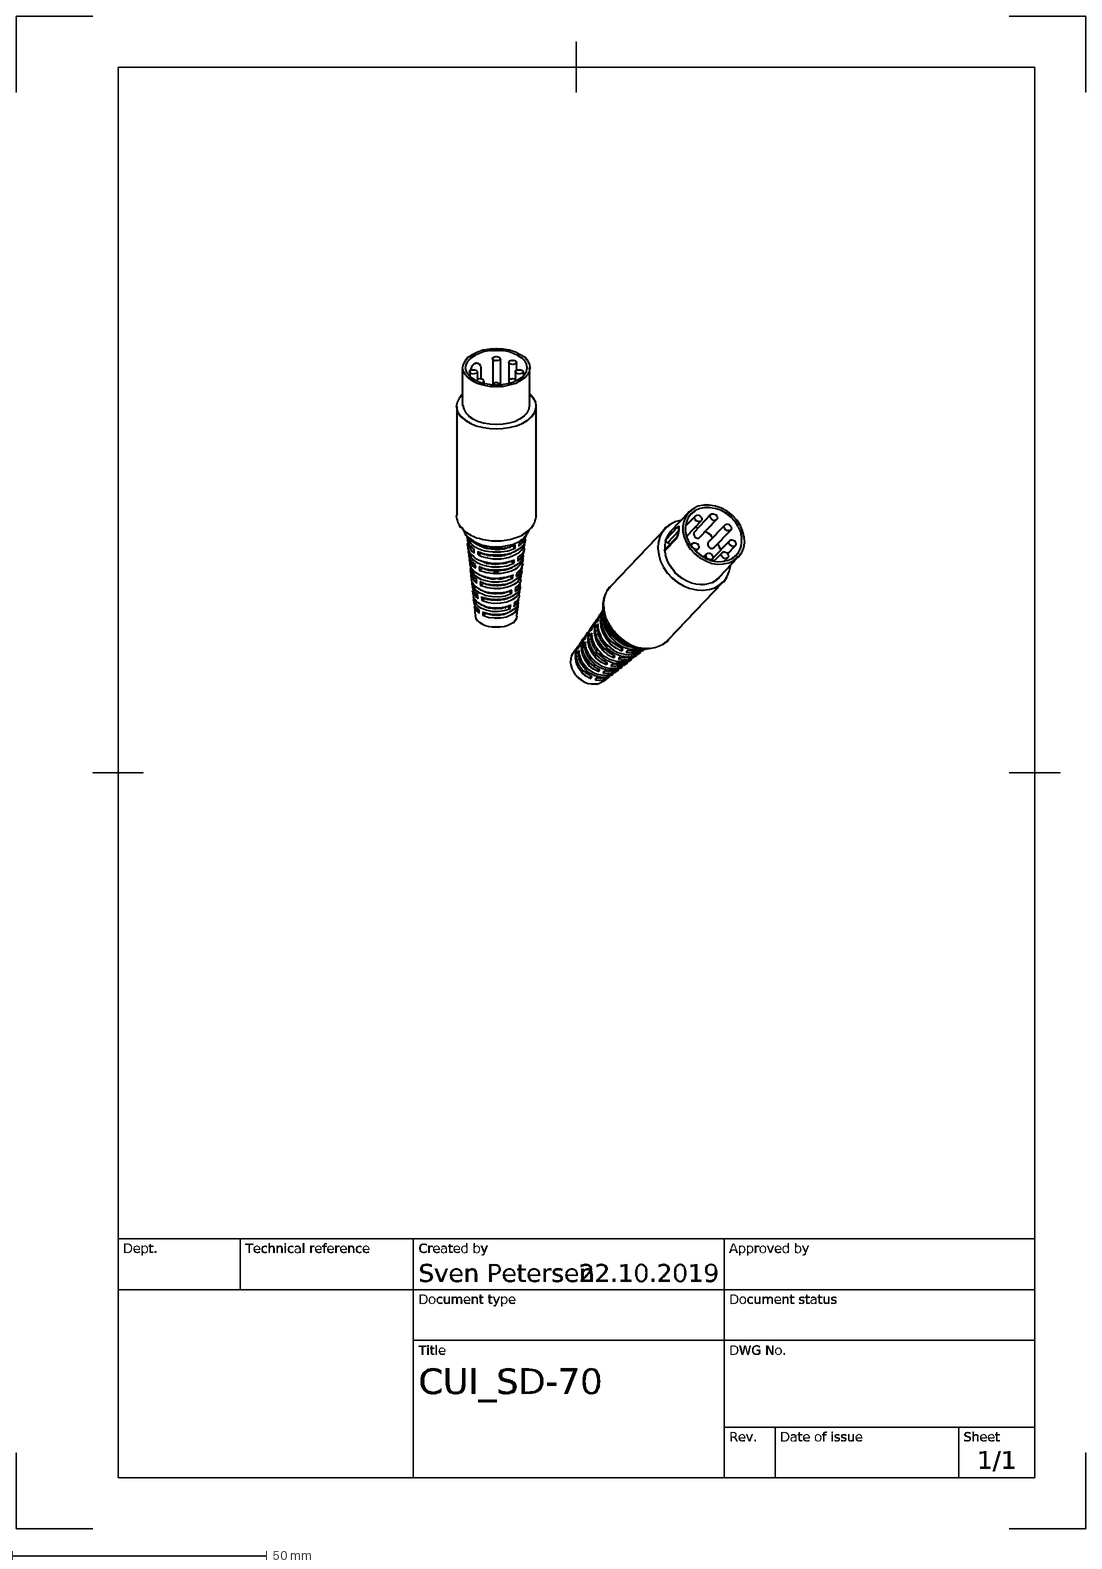
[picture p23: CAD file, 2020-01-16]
Rev. 1/Inkscape/CUI_SD-70 Zeichnung v1 Blatt1.dxf
22.10.2019
1/1
CUI_SD-70
Sven Petersen
Dept.
Technical reference
Created by
Approved by
Document type
Document status
Title
DWG No.
Rev.
Date of issue
Sheet

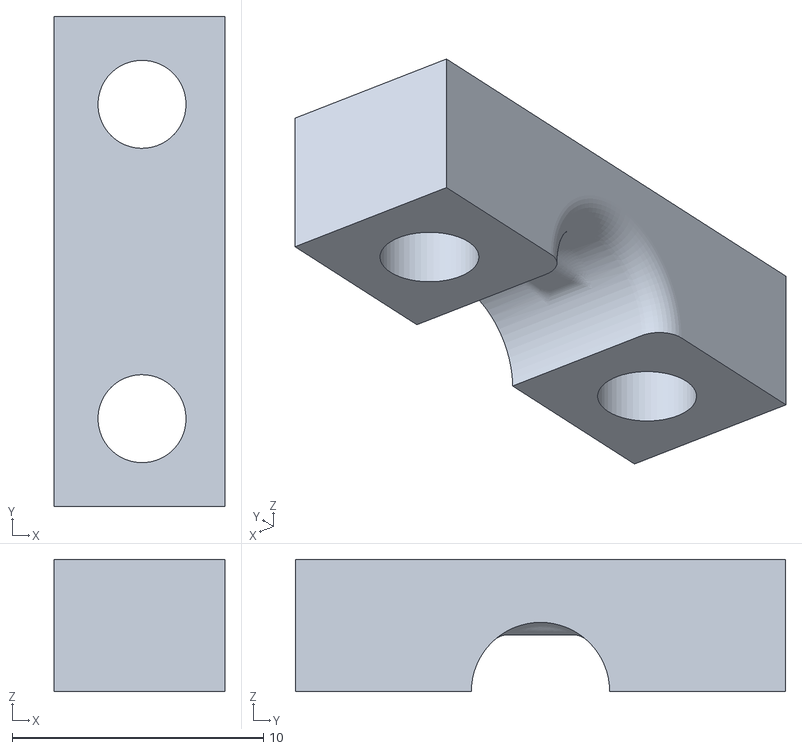
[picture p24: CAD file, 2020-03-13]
Case/Rev 0/stl/psug_strain_relief.stl
6.80 x 19.5 x 5.25

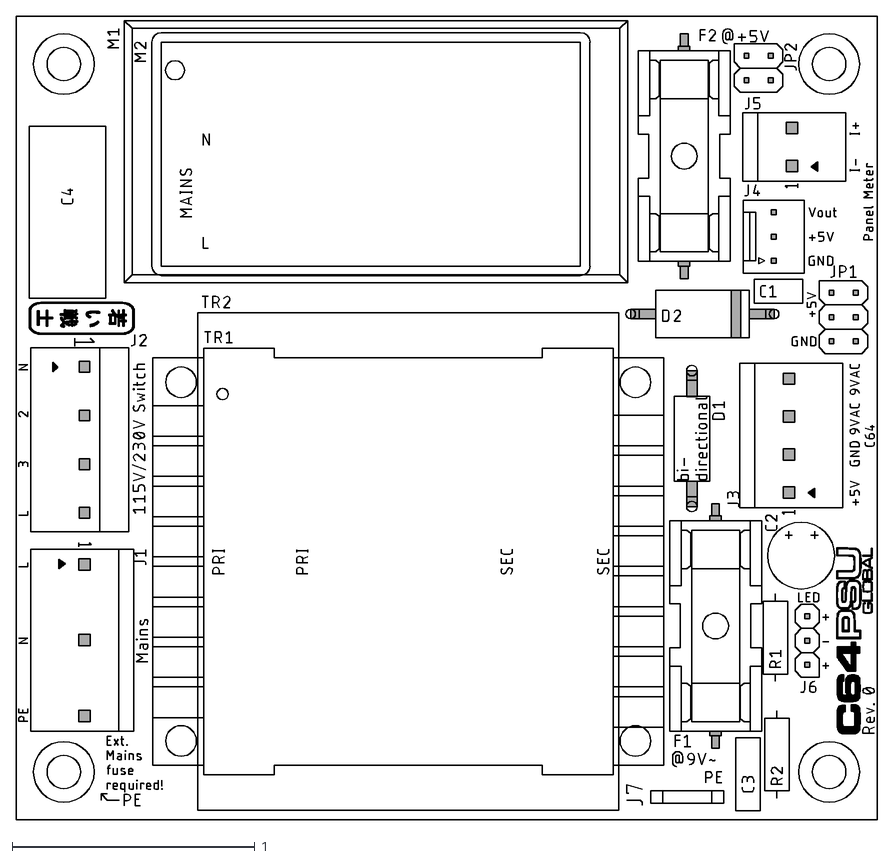
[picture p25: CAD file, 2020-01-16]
Rev. 1/dxf/C64_PSU_global.DXF
3.54 x 3.31

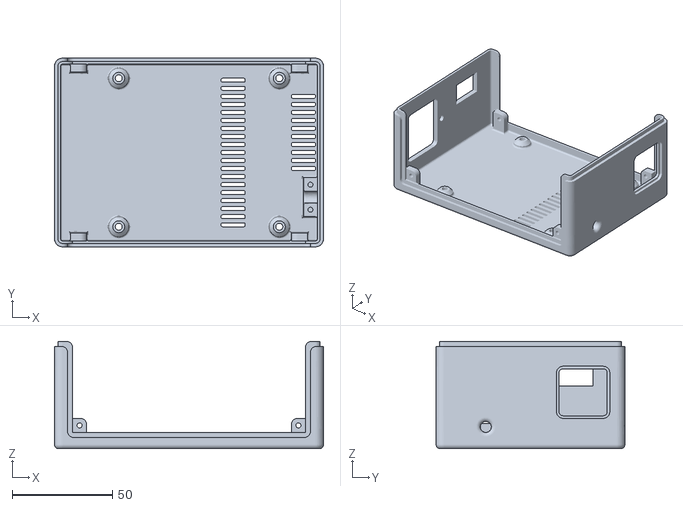
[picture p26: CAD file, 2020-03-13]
Case/Rev 0/stl/psug_bottom_shell_230V_only.stl
134.0 x 94.0 x 53.5

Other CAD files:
Case/Rev 0/stl/psug_bottom_shell.stl
Case/Rev 0/stl/bottom_shell_230V_only.stl
Rev. 1/dxf/T22205B436B.f3d

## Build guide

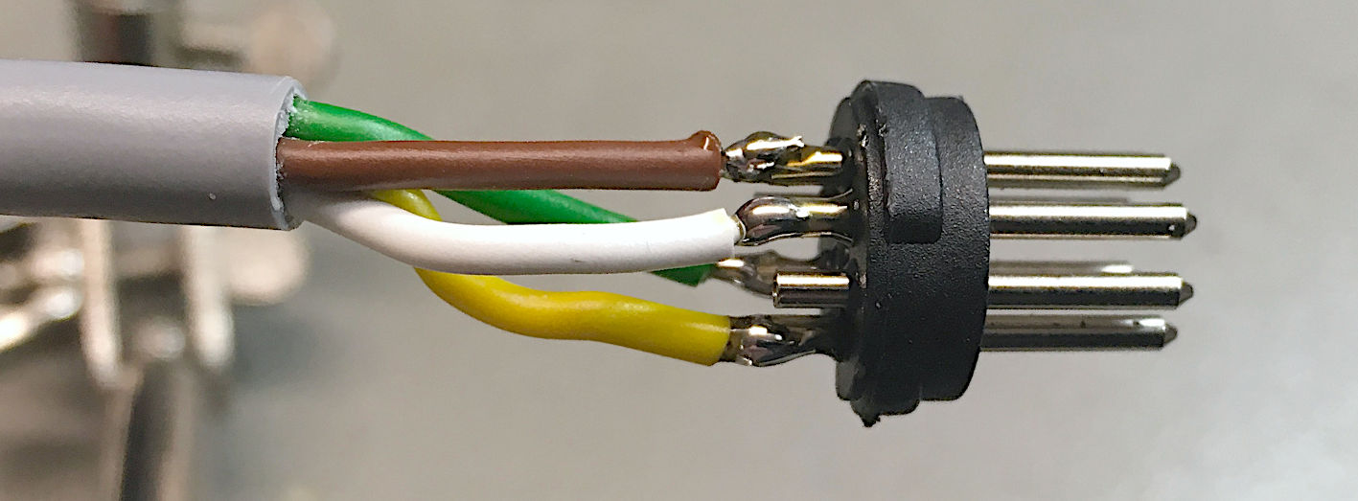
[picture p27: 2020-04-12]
Rev. 1/pictures/3748_soldered_din_connector.JPG

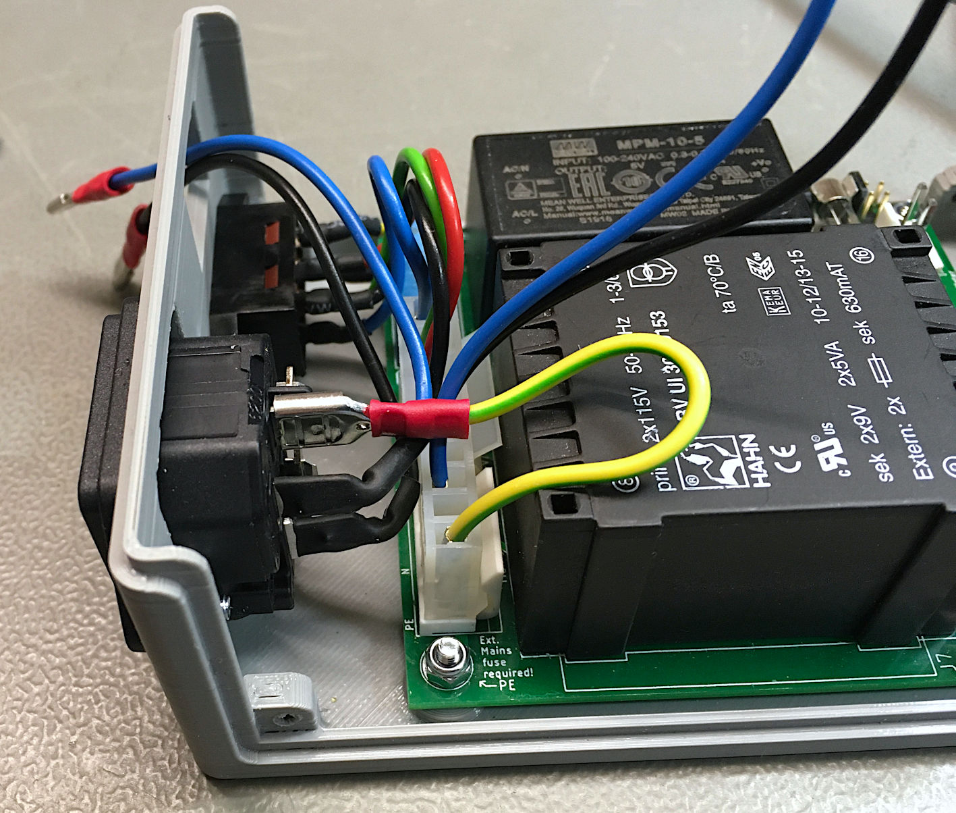
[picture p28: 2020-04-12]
Rev. 1/pictures/3725_mains_cable_installed.JPG

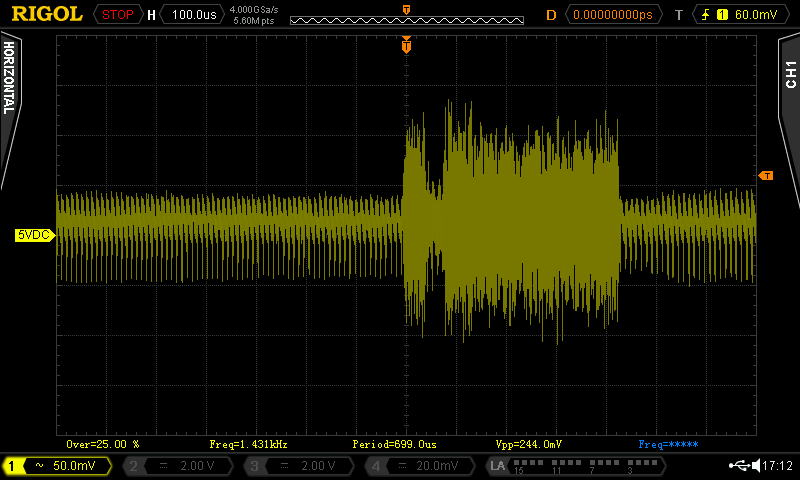
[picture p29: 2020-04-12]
Rev. 1/pictures/DS4_QuickPrint8.png

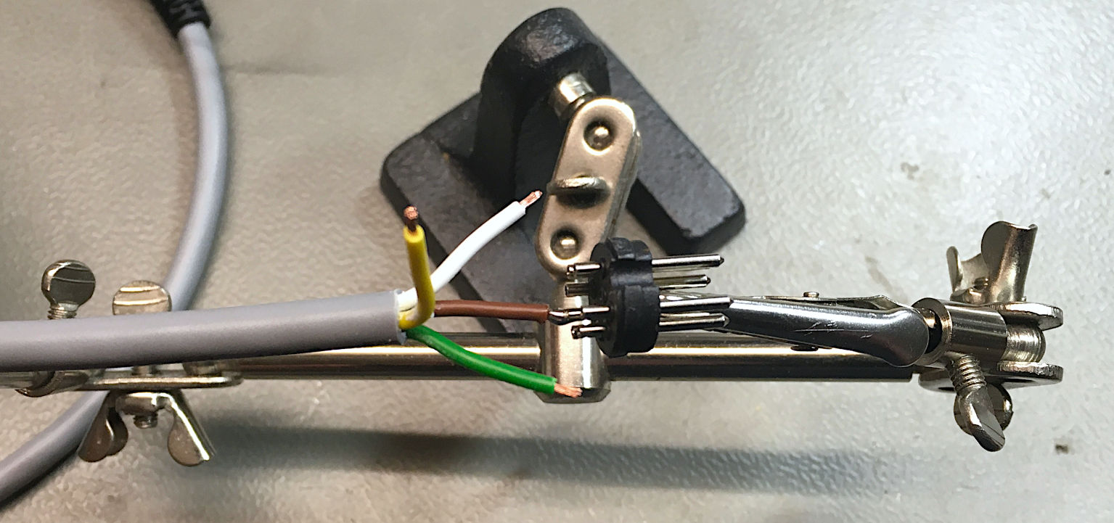
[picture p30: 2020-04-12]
Rev. 1/pictures/3746_soldering_din_connector.JPG

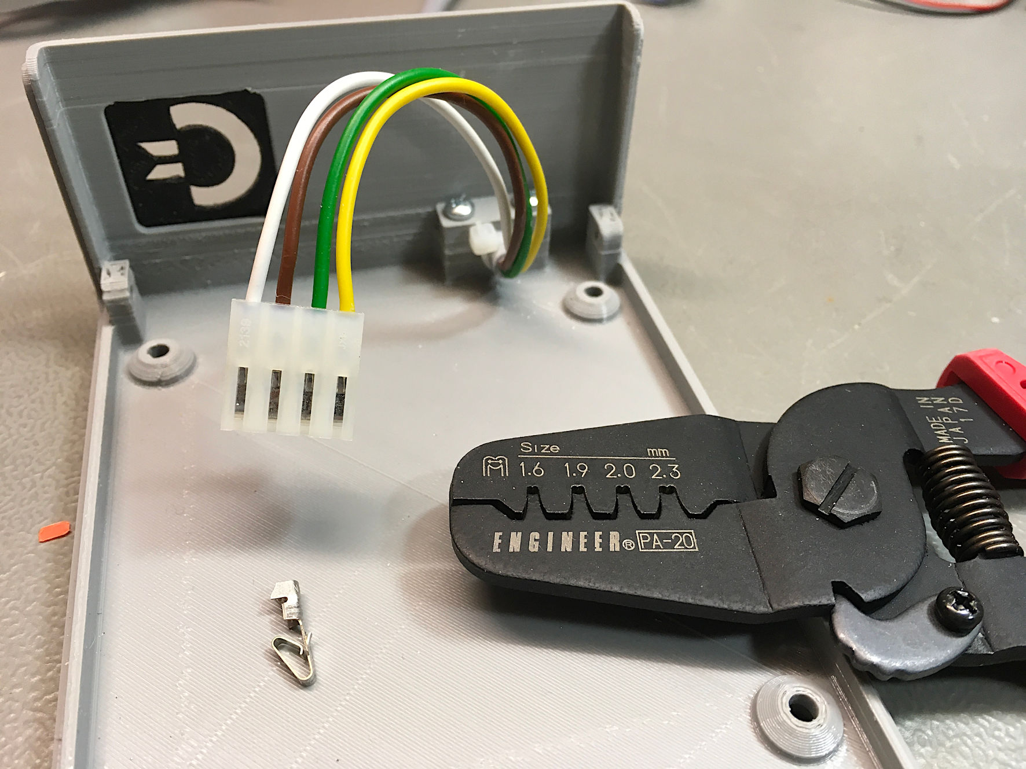
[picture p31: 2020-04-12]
Rev. 1/pictures/3712_output_cable_installed.JPG

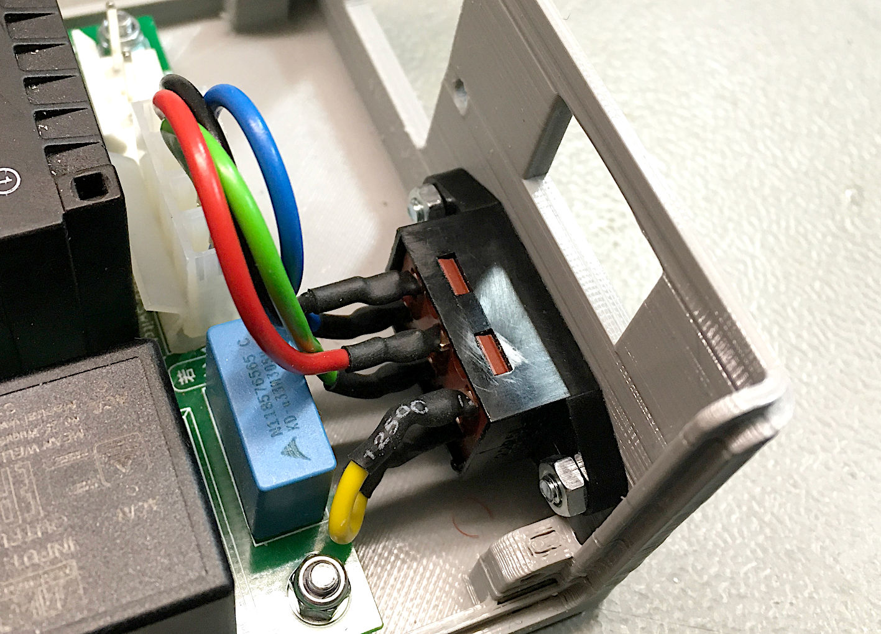
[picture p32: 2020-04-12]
Rev. 1/pictures/3723_voltage_selector_installed.JPG

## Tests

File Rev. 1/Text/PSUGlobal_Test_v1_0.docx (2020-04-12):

C64 PSU Global Rev. 1

Testing v1.0

# Devices under Test

The tests were conducted with two versions of the C64 PSU Global Rev. 0:

A. Version 115V/230V with TR1 (Hahn BV UI 304 0153) and AC/DC M2 (Mean Well MPM-10-5)
B. Version 230V with TR2 (BREVE TUFVASSONS TEZ10/D230/9V) and AC/DC M1 (RECOM RAC10-05SK/277)

The mains voltage was fix (230VAC) for most measurements. The voltage measurements were conducted with Rev. 0 and Rev. 1 of the PCB.

# Tests

## Testing Under Real Life Conditions

The setup for the function test was both versions, connected to a C64 with different ASSY No., an Ultimate II+ and a joystick switch was attached to the respective mainboard (Figure 1).

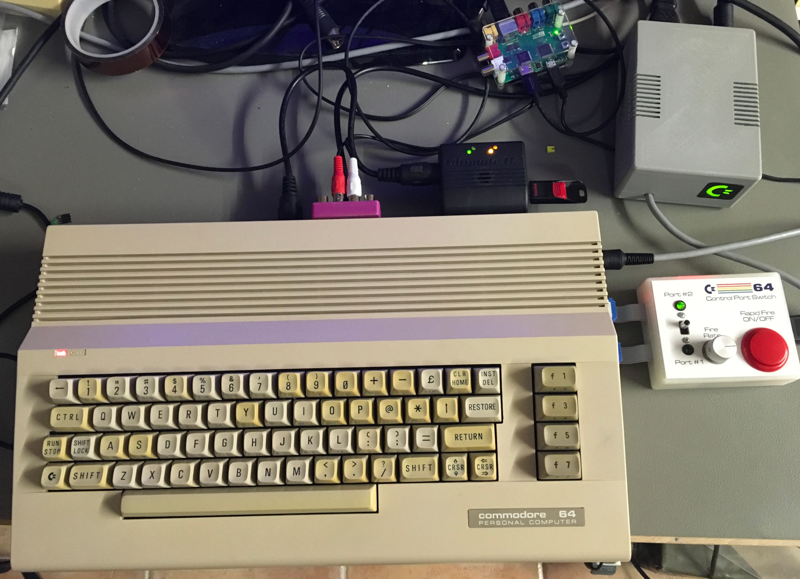
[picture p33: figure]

Figure 1: Testing the PSUs under real life conditions

C64 ASSY No. | Version A | Version B
250407 | C64 started, software loaded and worked properly | C64 started, software loaded and worked properly
250425 | C64 started, software loaded and worked properly | C64 started, software loaded and worked properly
250466 | C64 started, software loaded and worked properly | C64 started, software loaded and worked properly
250469 | C64 started, software loaded and worked properly | C64 started, software loaded and worked properly

## Output Voltages with and without Load (Rev. 0)

The load is a 4.7Ω resistor for the 5VDC and a 10Ω resistor for the 9VAC.

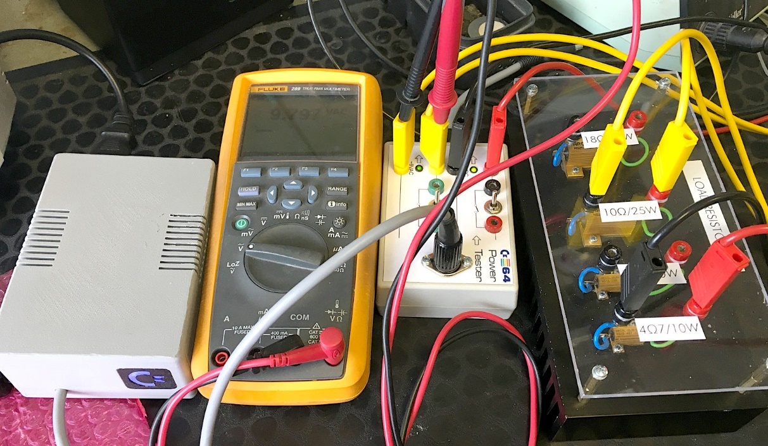
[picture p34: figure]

Figure 2: Test Setup

Device under Test (Rev. 0) | No Load | | Load
| 5VDC | 9VAC | 5VDC | 9VAC
Version A | 4.99V | 12.15V | 4.76V | 10.04V
Version B | 5.00V | 11.61V | 4.73V | 9.73V

The 9VAC output voltage is not critical, all voltages that are generated from it in the C64 are regulated. An output voltage of about 12V at no load is a normal value, which can be observed with transformers, which will output the nominal voltage at nominal load.

The value of the 5VDC is more critical here. The voltage drop of 250mV @ 1A is resulting from the voltage drop over the PCB tracks, the fuse, the connectors and the cable. It does not seem to be critical, since all ASSY Numbers, which are tried out, worked flawless over a longer time. Anyways, this voltage drop should be investigated further and minimized.

## Output Voltages with and without Load (Rev. 1)

In Rev. 1, the connection for a current panel meter was dropped, since the accuracy of those panel meters was considered to be not sufficient. This should have an effect on the voltage drop on the PCB. Thus, the measurements conducted with Rev. 0 were repeated with Rev. 1 to observe the effects of the modification.

Voltage | No load | Load | Current
+5VDC | 4.995V | 4.803V | 0.989A
9VAC | 12.500VAC | 10.234VAC | 1.008A

The voltage-drop (192mV) is now tracked within the system.

The voltage-drop measured directly across the 5V fuse F2 was 68.5mV (of which 10mV are caused by the fuse holder). The complete voltage-drop measured over pin 1 and pin 2 of the output jack J3 was 100mV. The output cable (88cm) contributed another 92mV. So, the cable contributes about half of the voltage drop. An AWG21/0.5mm² cable provides a resistance of 43.4Ω per meter. Since both, the +5V and the GND wire have to be taken into account, an 88cm cable has a resistance 76.4Ω. The calculated voltage drop is about 76mV. The connector of the test box might be responsible for the difference.

Conclusion: The output cable should be as short as possible. A different fuse type might have a less voltage-drop (a not approved 10A fuse produces only 5mV of drop).

The board design is good. 2oz of copper instead of 1oz are not worth the extra price, since the copper traces provide the least part of the voltage drop.

The measurements were carried out with an eevBlog 121GW multimeter.

## Ripple measurement

The +5V output voltage was inspected with a scope (Rigol MSO4024). A load of 4.7Ω was applied to this output.

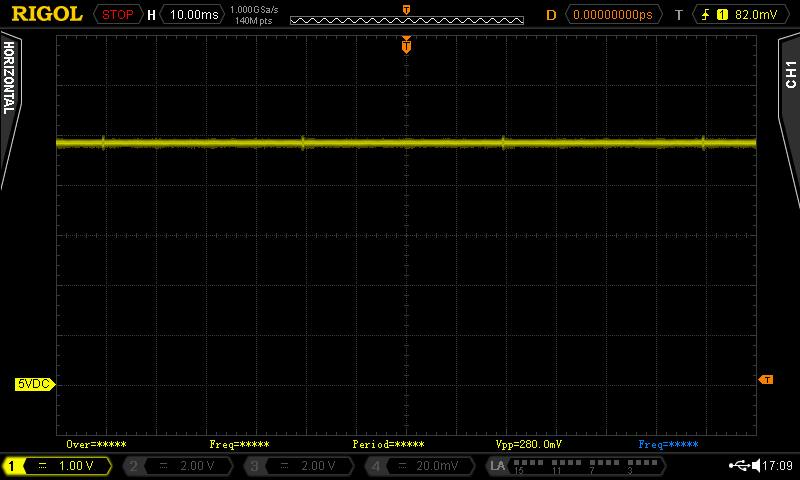
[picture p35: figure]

Figure 3: 5VDC (DC coupling, 1V/div and 10ms/div)

A voltage spike was found every 40ms. This should now be investigated further. #

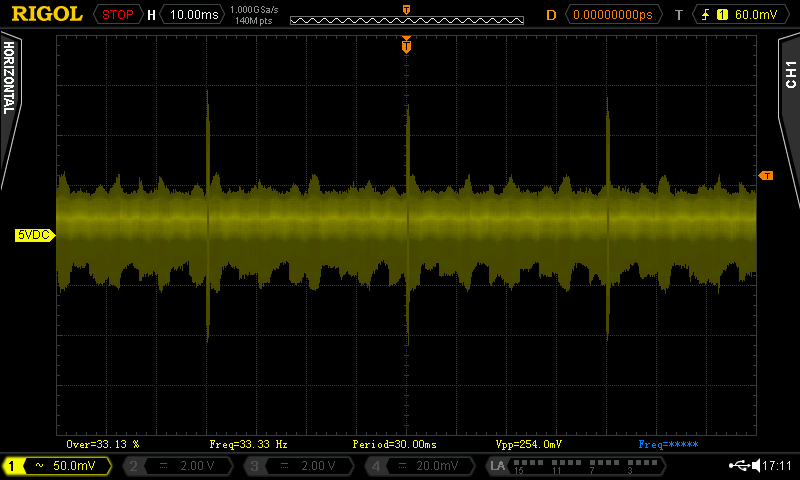
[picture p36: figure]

Figure 4: AC coupling, 50mV/div and 10ms/div


Figure 5: AC coupling, 50mV/div, 100µs/div

The spike or burst that occurs every 40ms has 244mVPP (peak to peak voltage) for about 430µs, while the remaining time, the ripple says within 100mVPP. This is not unusual. The input filter of the C64 might flatten this further. A measurement was not conducted.

## 115V mains voltage test (Rev. 0)

The test was conducted with the switchable version of the power supply (Version A), which was connected to an adjustable isolating transformer (Figure 6).

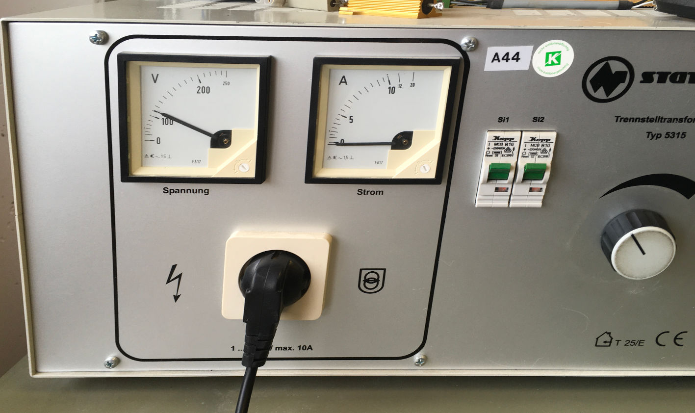
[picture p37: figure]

Figure 6: Adjustable isolating transformer

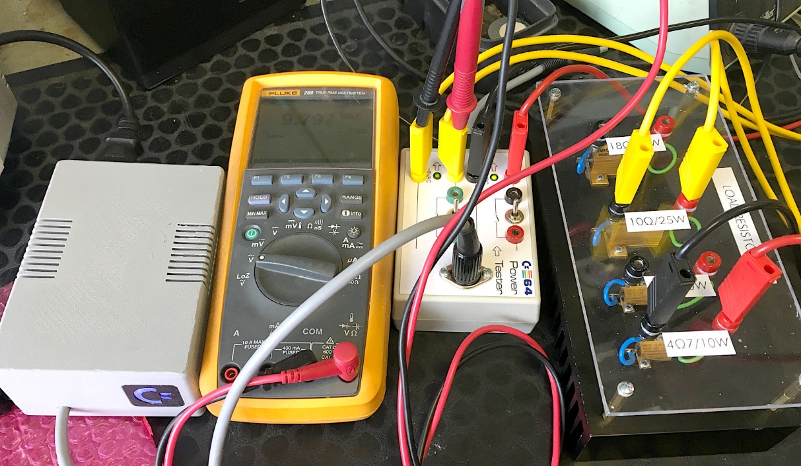
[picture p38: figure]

Figure 7: Test Setup for the 115VAC mains test

The isolating transformer was adjusted to approximately 110V. As expected, the +5VDC reading did not differ from the reading at 230V mains voltage. The 9VAC showed 9.8VAC with a 10Ω load. This test was also a proof of concept for the mains voltage selector switch.

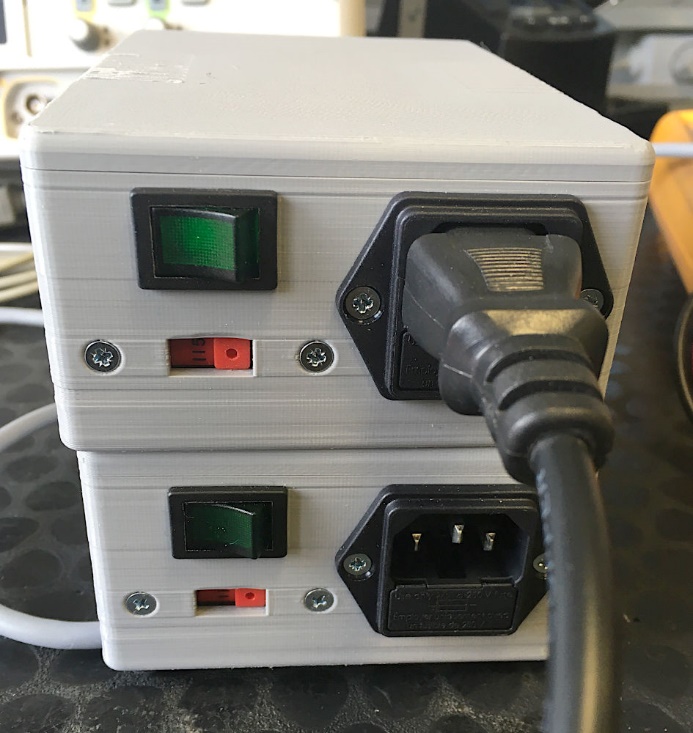
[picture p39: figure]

Figure 8: Dim power switch

At 110VAC, the illuminated power switch was not bright at all (Figure 8). This was expected, since the switch was designed for 230V. This is not harmful, but as a conclusion, for 115V, an illuminated switch is not required.

## Thermal Tests (Rev. 0)

The thermal behavior of the PSU Global might be critical, so this was investigated in depth. The critical temperature of PLA is 55°C to 60°C (when it softens) depending on the type. Since it was a goal to stay away from the critical temperature, it was repeated several times with modified cases. First, more ventilation slots were added in a second step the case has been made higher to get farther away from the transformer, which turned out to radiate most of the heat. A significant difference could not be achieved with the modifications of the case, though.

The temperatures were measured with a thermo couple positioned in the middle of the top shell right above the transformer and the (5V) AC/DC converter (Figure 9).

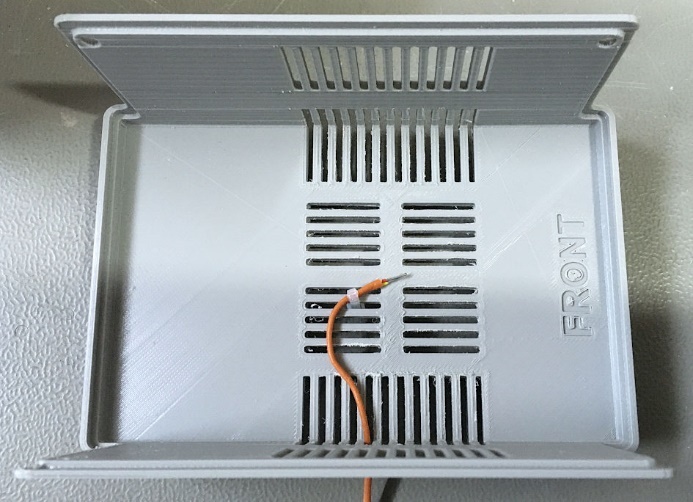
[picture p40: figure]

Figure 9: Position of the thermo-couple

The voltages were loaded with 4.7Ω on +5V and 10Ω on 9VAC and the temperatures were documented over the course of the test.

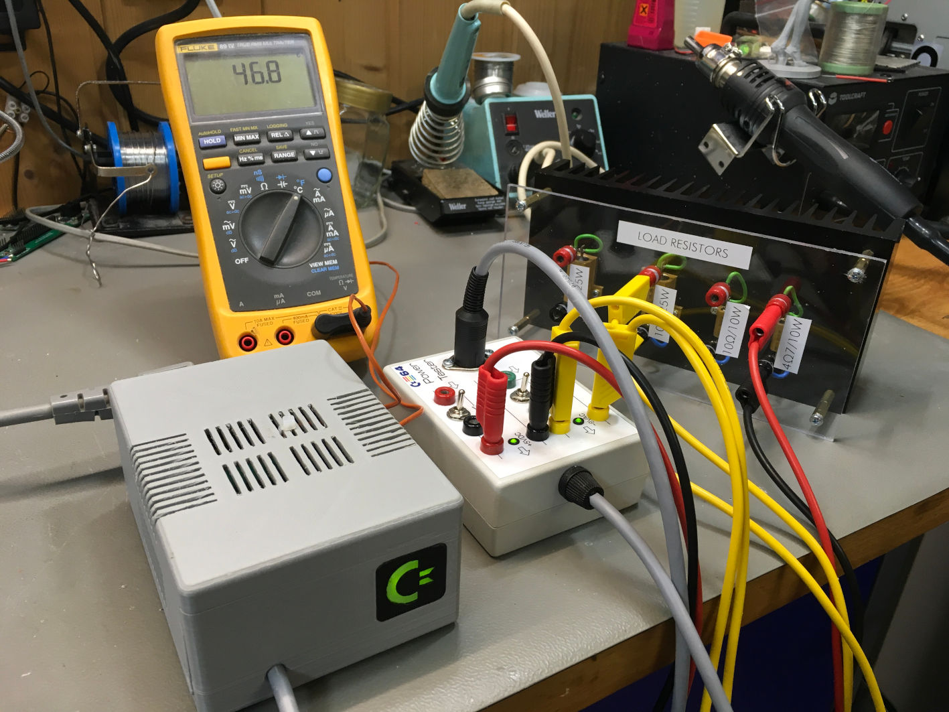
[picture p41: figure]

Figure 10: Test Setup (resistor load)

Measurement | #1 | #2 | #3
Time | 0:00h | 0:28h | 2:16h
Temperature | 22.2°C | 34.1°C | 46.7°C

In a second test, a real-life setup was tested. The highest current consumption is attained with an ASSY250407 C64. Further, an Ultimate II+ and a control port switch were connected to this computer. The temperatures were measures with the same setup like before.

Measurement | #1 | #2 | #3 | #4
Time | 0:00h | 0:54h | 1:49h | 2:29h
Temperature | 22.7°C | 39.3°C | 42.5°C | 43.5°C

Conclusion of the temperature measurements: With the resistor load, the temperature rises to about 8°C below the lowest critical temperature (55°C) defined before. The ambient temperature was about 22°C. Thus, at an ambient temperature of 30°C, the critical temperature is reached.

With a real-life load, the temperature stays 11°C below the 55°C (ambient temperature 23°C). Thus, the critical temperature is reached at an ambient temperature of 34°C.

The critical temperature for the electronic components inside is 70°C, which is by far not reached.

Recommendation: do not use the power supply at an ambient temperature of >30°C if the case is made from PLA or use ABS for printing, which has a much higher critical temperature.

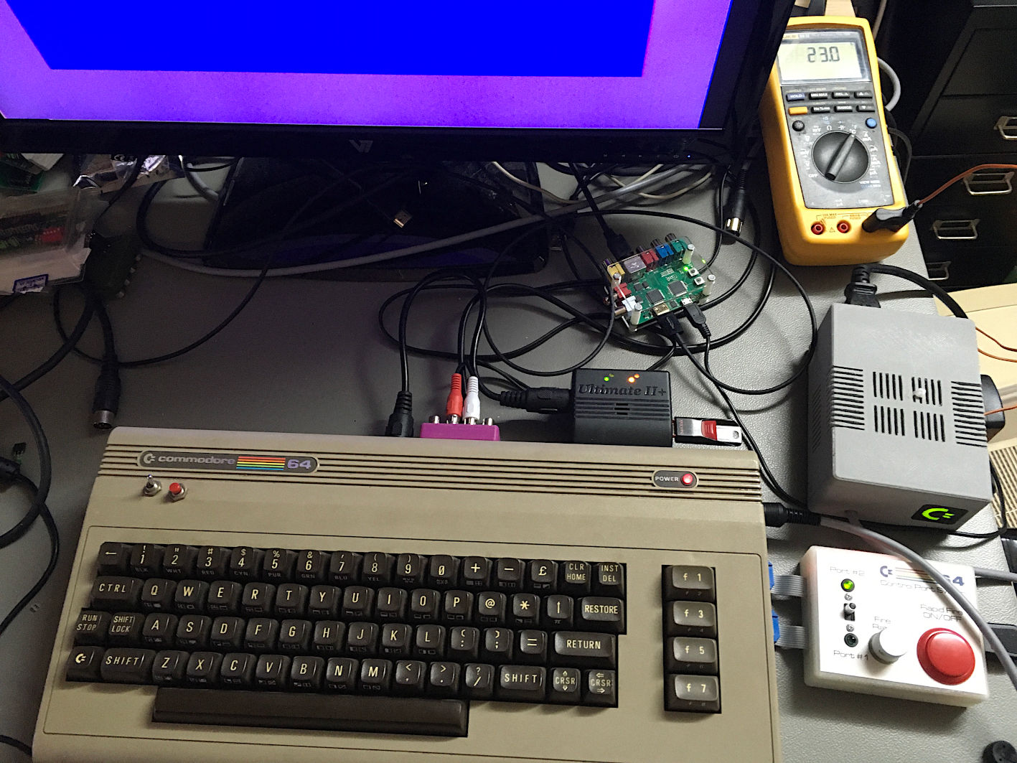
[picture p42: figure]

Figure 11: Real-life thermal test setup

# Conclusion

Both, Rev. 0 and Rev. 1 are functional. The smaller voltage-drop of Rev. 1 is a small improvement. The case should be printed with ABS for an improved temperature range.

The all tested C64 were working without any problems while powered. Note: the original C64 PSU was set to about 5.2V or 5.3V. It is not sure, if this was really required or just a precaution. The AC/DC module used for this project is used for other C64 PSUs, too. It cannot be adjusted to a higher output. Its output is 5.00V. It might be possible, that a few C64s, which work perfectly with the original power supply do not work with this PSU (or any other, that uses AC/DC modules). In this case, it might be interesting to replace the fuse with a higher rated fuse (the AC/DC modules have an overload protection) and keep the output cable as short as possible.

PSUGlobal_Test_v1_0.docx 12.04.2020 17:25 Drafted by Sven Petersen Page 2 of 2 Doc.-No.: 133-6-03-01.0

PSUGlobal_Test_v1_0.docx 12.04.2020 17:25 Drafted by Sven Petersen Page 1 of 1 Doc.-No.: 133-6-02-00

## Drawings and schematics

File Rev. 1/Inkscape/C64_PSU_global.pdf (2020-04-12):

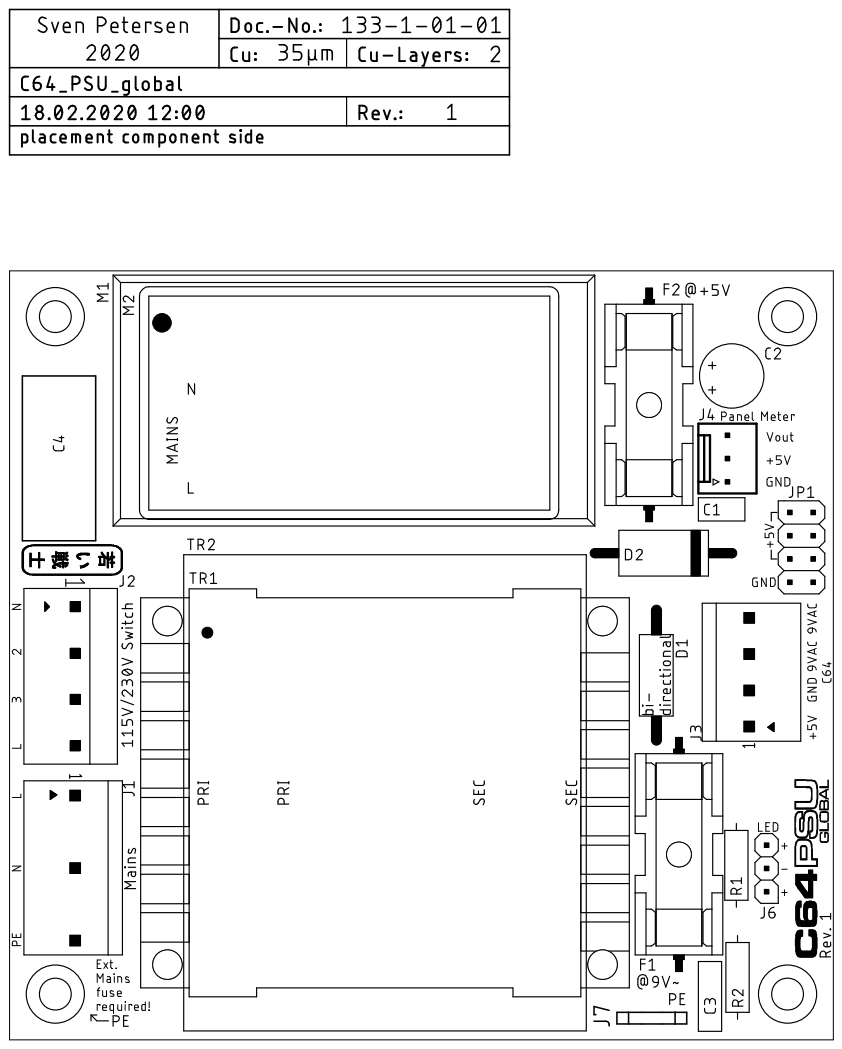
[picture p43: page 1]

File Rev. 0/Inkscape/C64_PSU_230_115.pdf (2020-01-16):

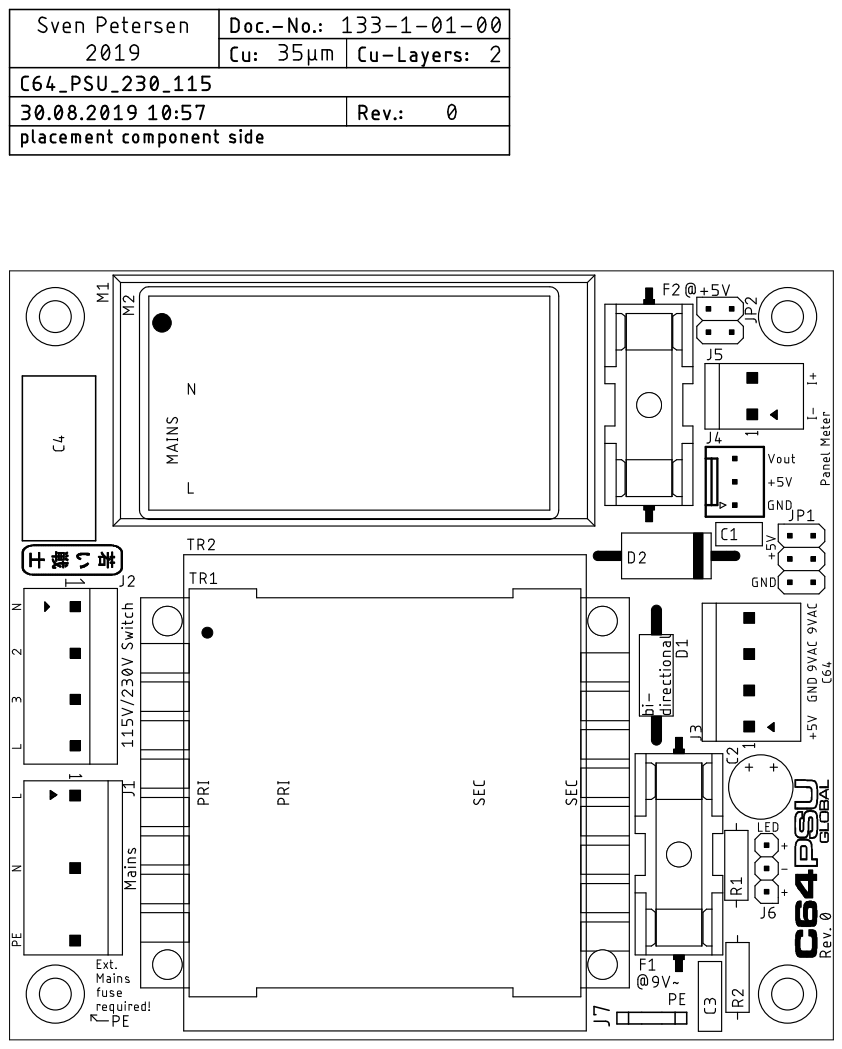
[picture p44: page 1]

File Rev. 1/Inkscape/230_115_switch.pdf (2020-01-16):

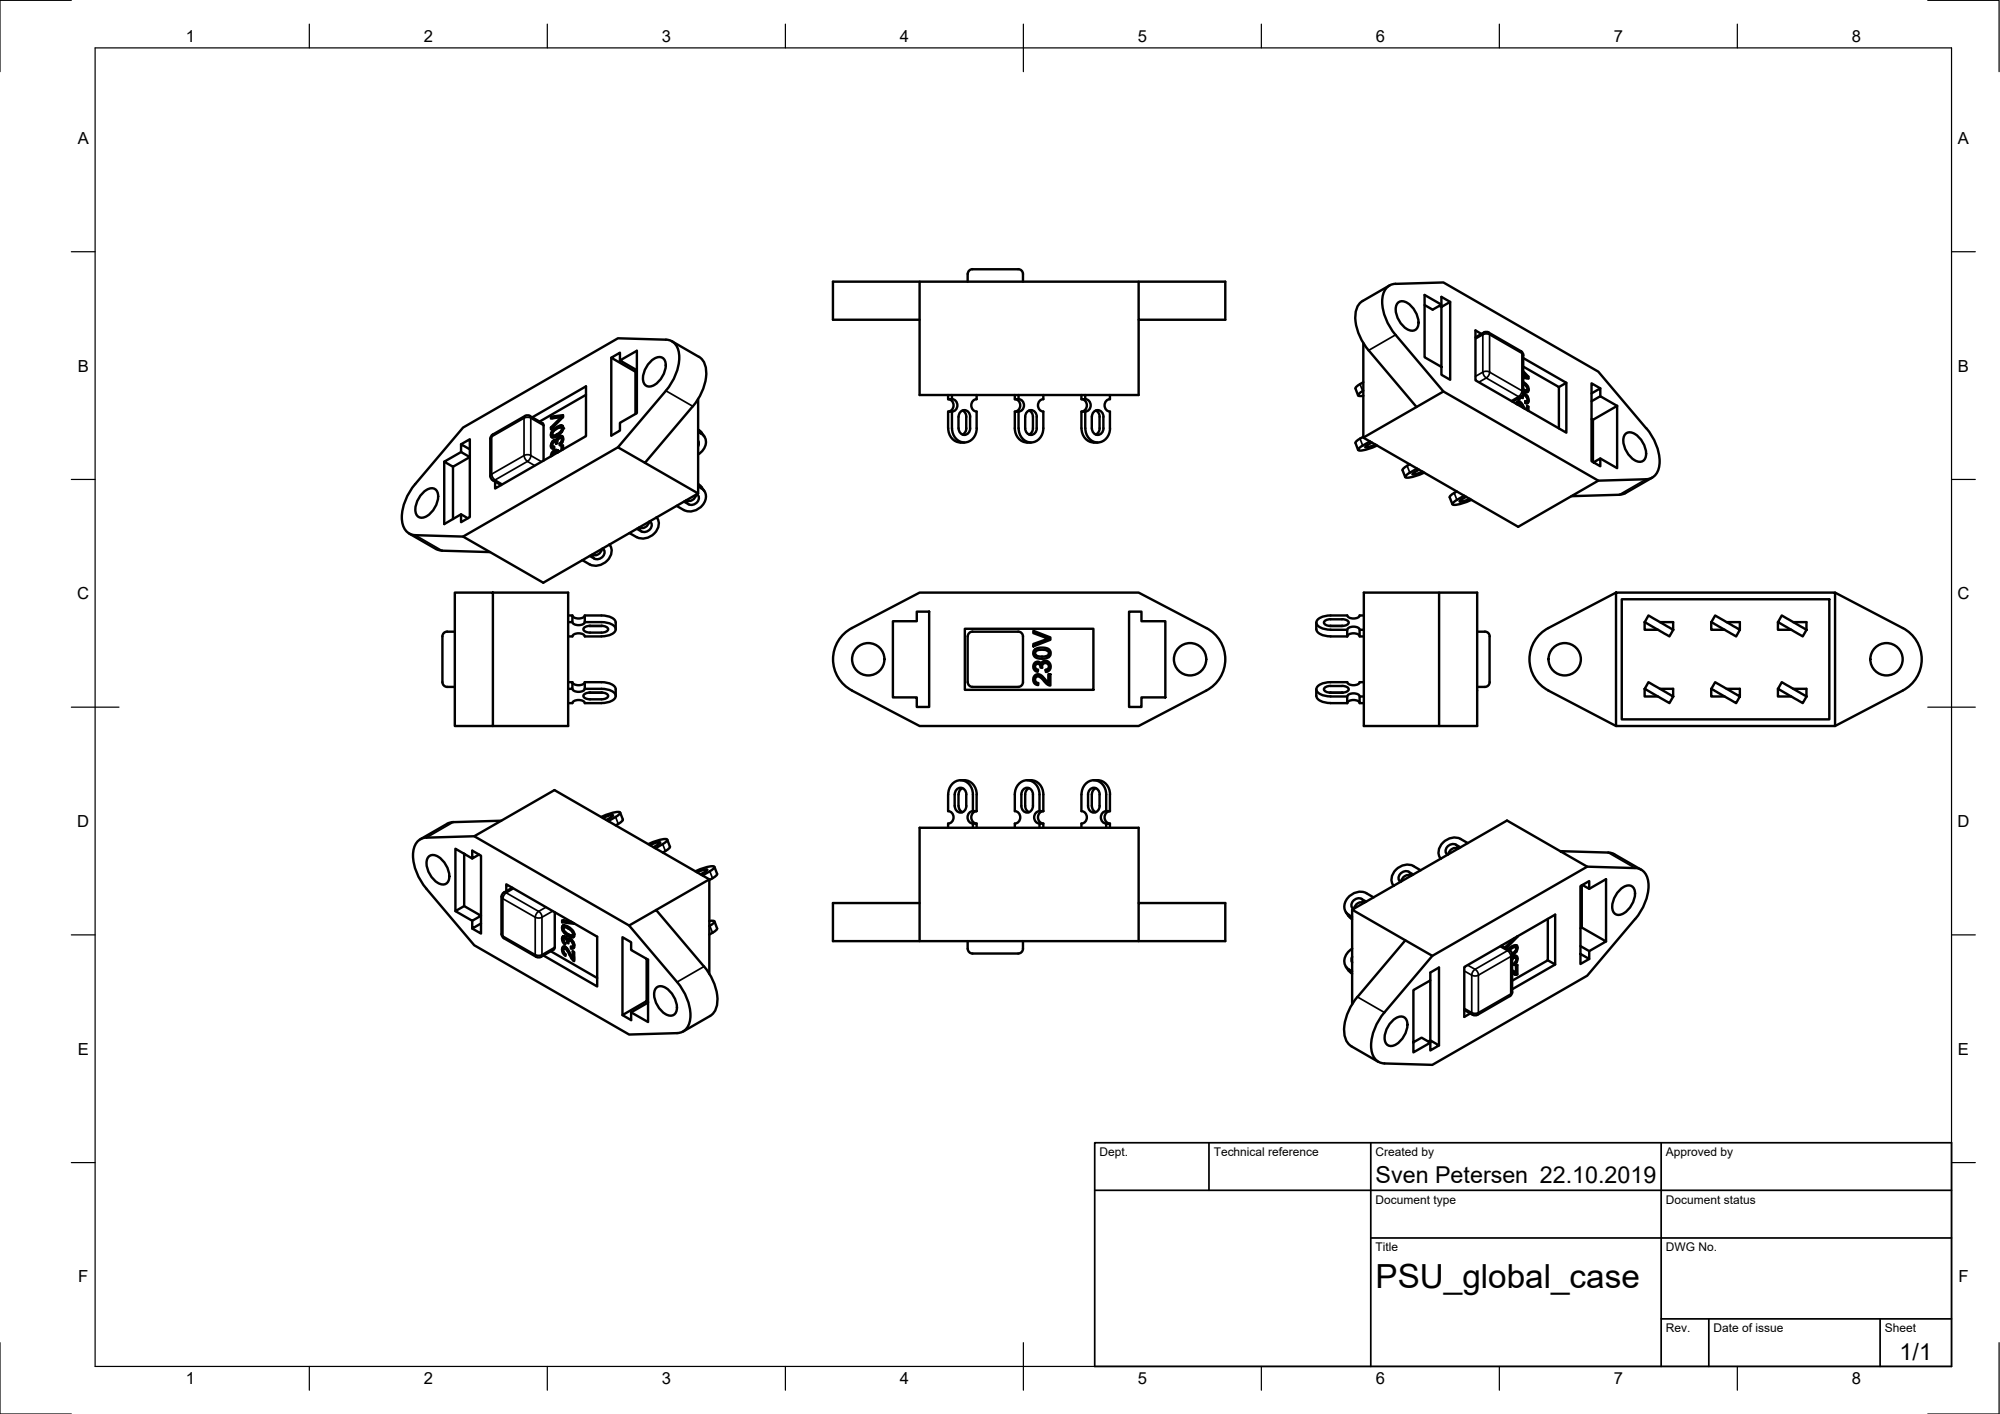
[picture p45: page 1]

Dept. | Technical reference | Created by Sven Petersen 22.10.2019 | Approved by

Document type | Document status

Title PSU_global_case | DWG No.

Rev. | Date of issue | Sheet 1/1

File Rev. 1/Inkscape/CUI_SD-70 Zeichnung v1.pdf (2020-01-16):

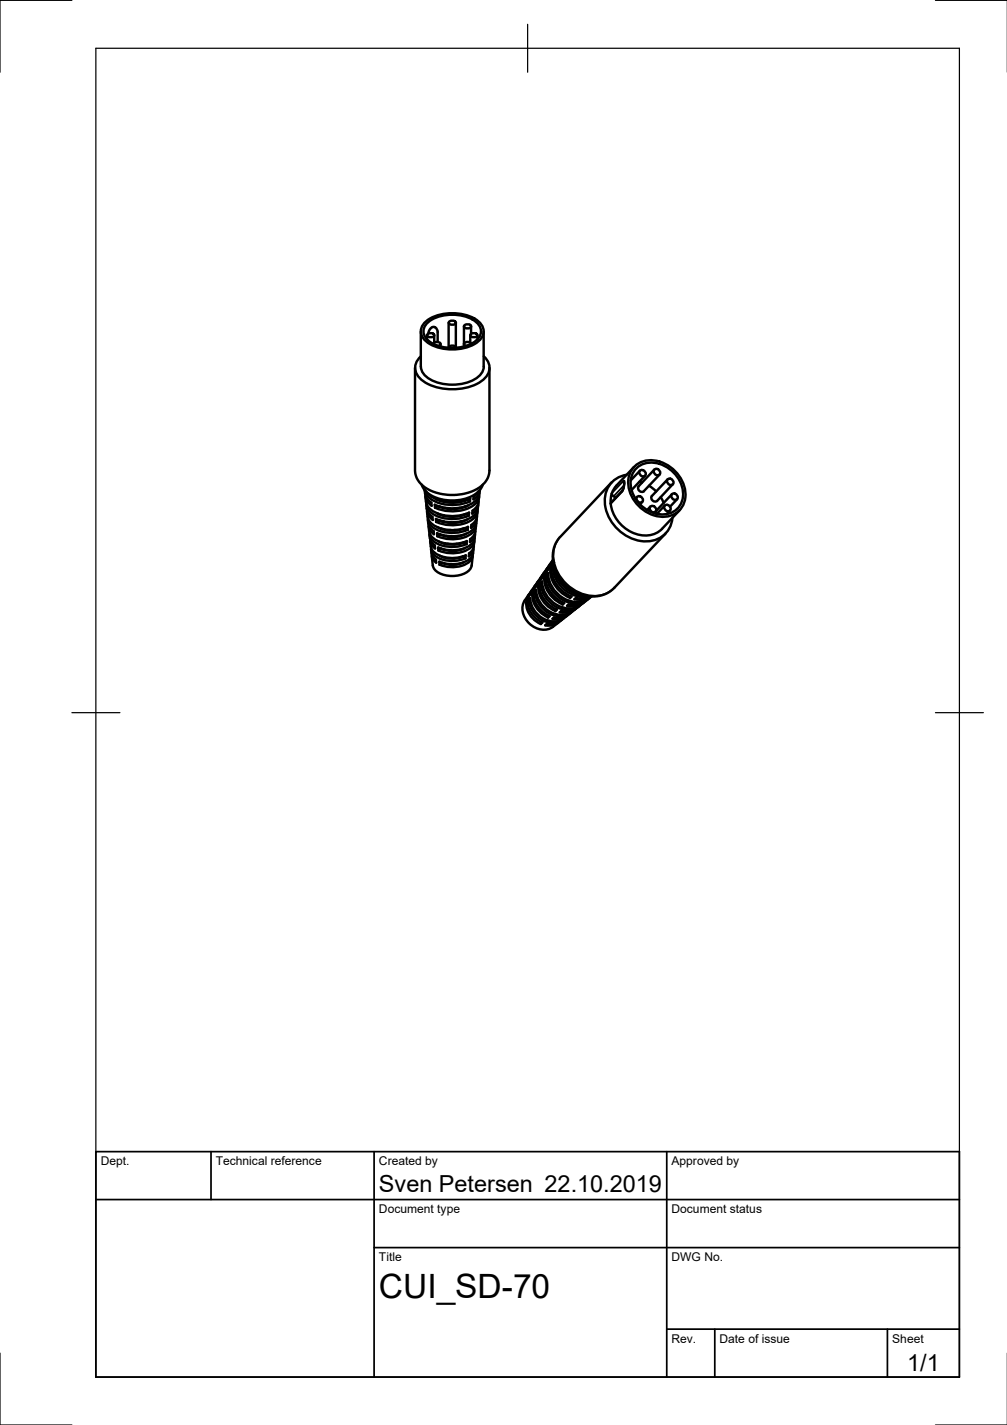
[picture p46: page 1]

Dept. | Technical reference | Created by Sven Petersen 22.10.2019 | Approved by

Document type | Document status

Title CUI_SD-70 | DWG No.

Rev. | Date of issue | Sheet 1/1

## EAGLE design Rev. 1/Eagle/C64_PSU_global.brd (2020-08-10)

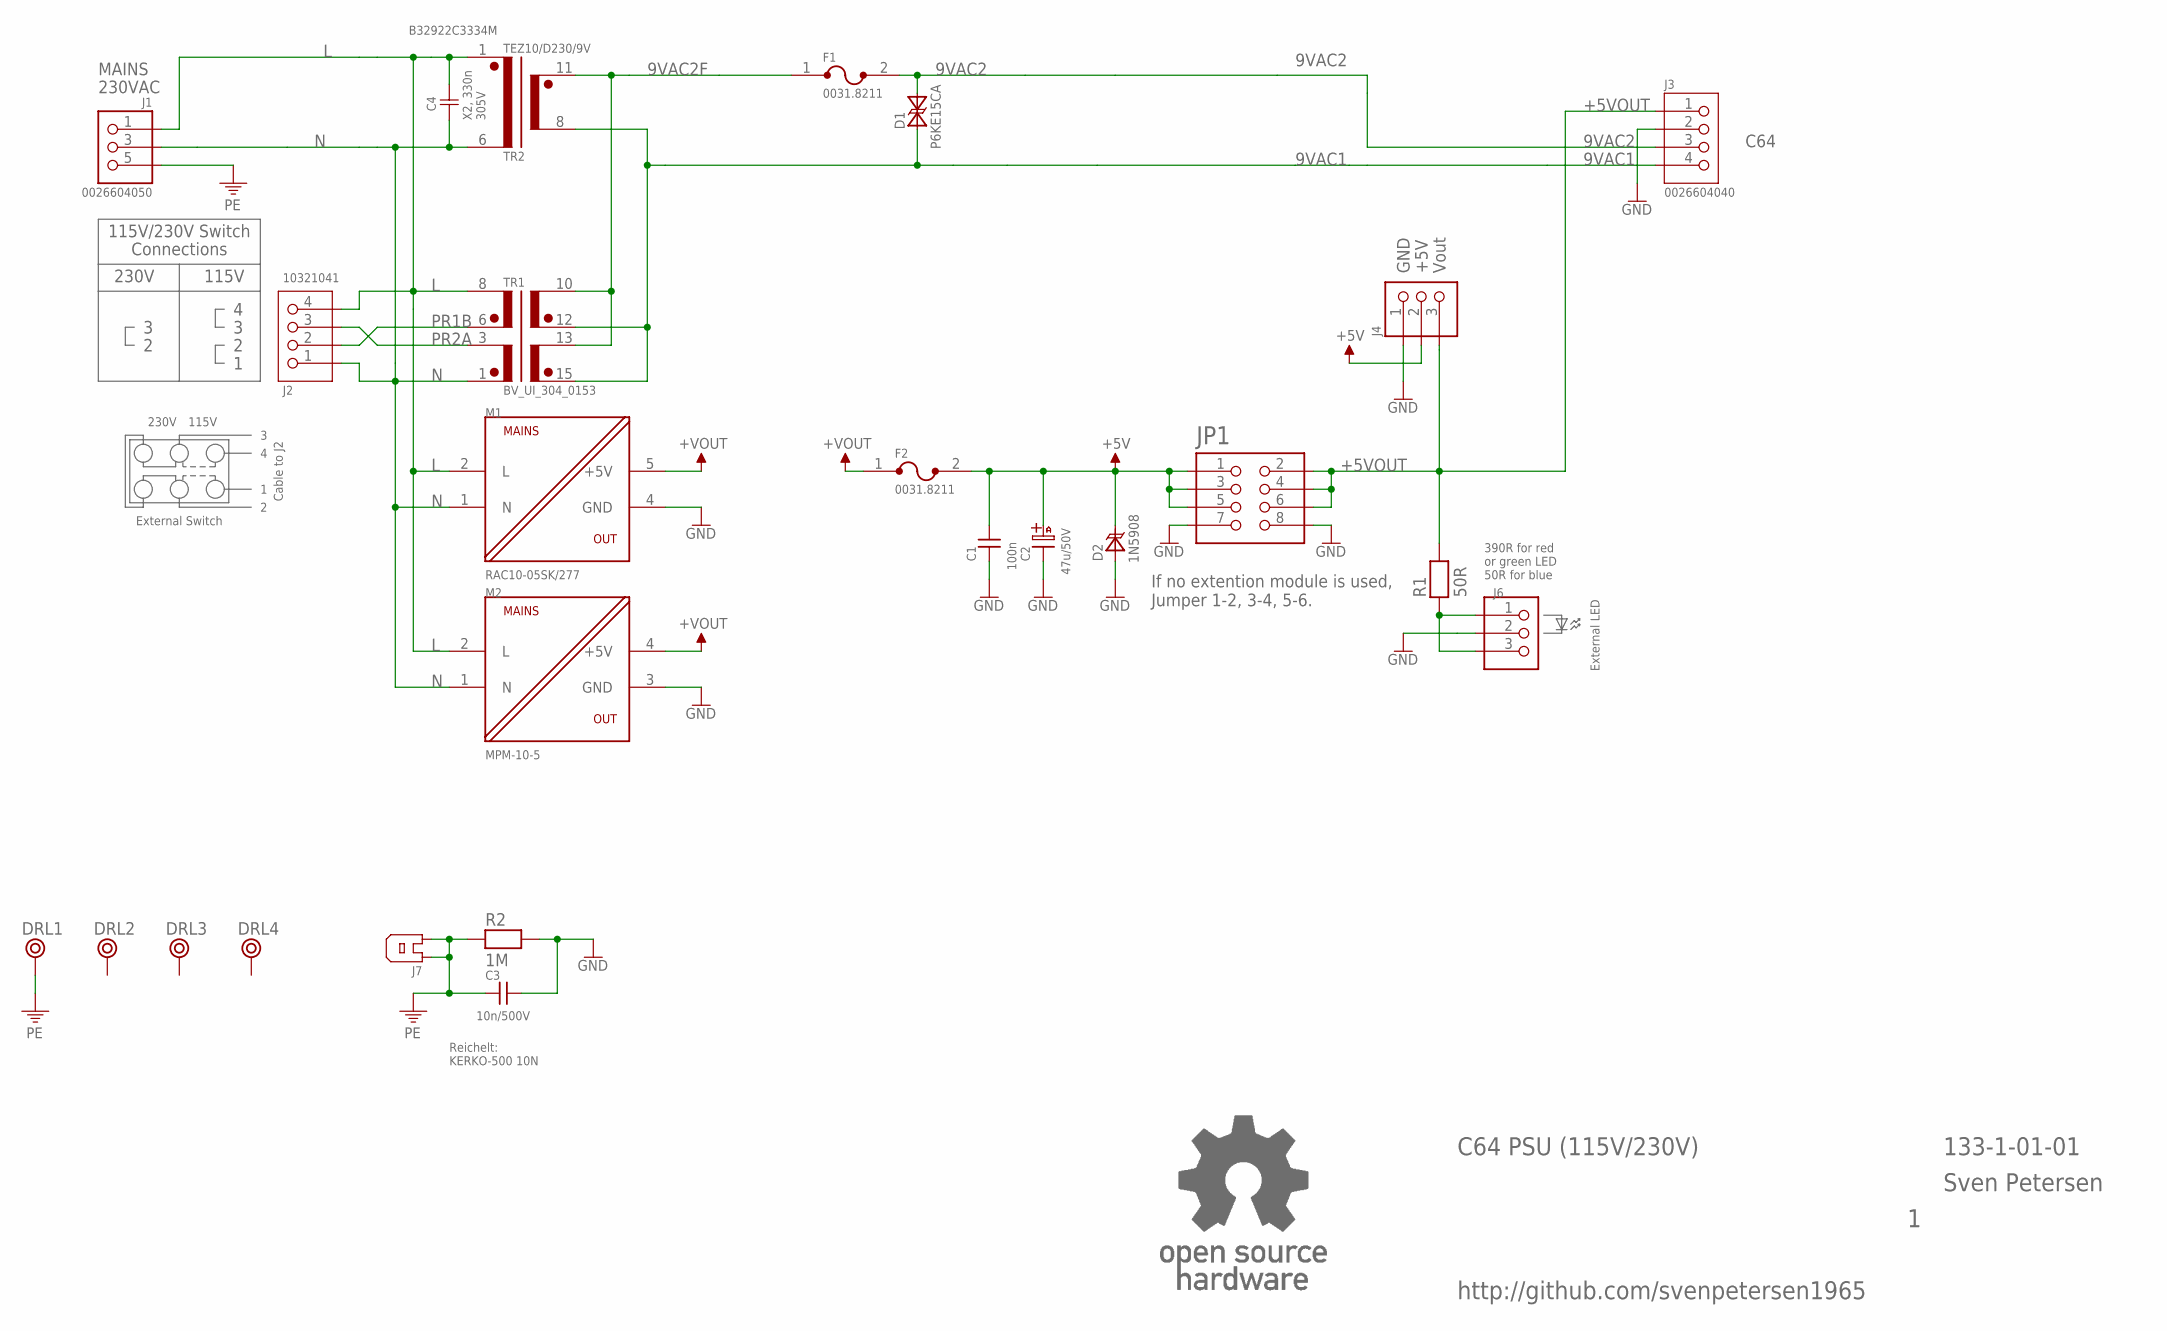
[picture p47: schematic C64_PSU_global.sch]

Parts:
C1: 100n; C-2,5
C2: 47u/50V; C07/2,5
C3: 10n/500V; C-5
C4: B32922C3334M; C-18X8-RM15
D1: P6KE15CA; CB417NP
D2: 1N5908; CB429
DRL1: BOHR3,5OR; BOHR3,5_OHNE_RESTRICT
DRL2, DRL3, DRL4: BOHR3,5
F1, F2: 0031.8211
J1: 0026604050; SPOX_3.96_5P3
J2: 10321041; SPOX_5.08_4P
J3: 0026604040; SPOX_3.96_4P
J4: 6410-3P
J6: PINHD-1X3; 1X03
J7: FLA6,3
JP1: PINHD-2X4; 2X04
M1: RAC10-05SK/277; RAC10-K/277
M2: MPM-10-5; MPM10
R1: 50R; R-10
R2: 1M; R-10
TR1: BV_UI_304_0153; UI30
TR2: TEZ10/D230/9V; TEZ10
U$25: OPEN_SOURCE_HW; OPENHW

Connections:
9VAC1: D1.A (A1), J3.4, TR1.12 (SEC1B), TR1.15 (SEC2B), TR2.8 (SEC11)
9VAC2: D1.K (A2), F1.2, J3.3
9VAC2F: F1.1, TR1.10 (SEC1A), TR1.13 (SEC2A), TR2.11 (SEC12)
+5V: C1.2, C2.A (+), D2.K, F2.2, J4.2, JP1.1, JP1.3, JP1.5
+5VOUT: J3.1, J4.3, JP1.2, JP1.4, JP1.6, R1.2
+VOUT: F2.1, M1.5 (+5V), M2.4 (+5V)
GND: C1.1, C2.K (-), C3.2, D2.A, J3.2, J4.1, J6.2, JP1.7, JP1.8, M1.4 (GND), M2.3 (GND), R2.2
L: C4.2, J1.1, J2.4, M1.2 (L), M2.2 (L), TR1.8 (PRI1A), TR2.1 (PRI2)
N: C4.1, J1.3 (2), J2.1, M1.1 (N), M2.1 (N), TR1.1 (PRI2B), TR2.6 (PRI1)
unnamed: J6.1, J6.3, R1.1
PE: C3.1, DRL1.P$1, J1.5 (3), J7.1, J7.2, R2.1
PR1B: J2.2, TR1.6 (PRI1B)
PR2A: J2.3, TR1.3 (PRI2A)

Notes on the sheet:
External LED
390R for red or green LED 50R for blue
Reichelt: KERKO-500 10N
If no extention module is used, Jumper 1-2, 3-4, 5-6.
+5V
GND
Vout
230VAC
X2, 330n 305V
MAINS
C64
115V/230V Switch
230V
115V
Connections
C64 PSU (115V/230V)
133-1-01-01
Sven Petersen
Cable to J2
External Switch
http://github.com/svenpetersen1965

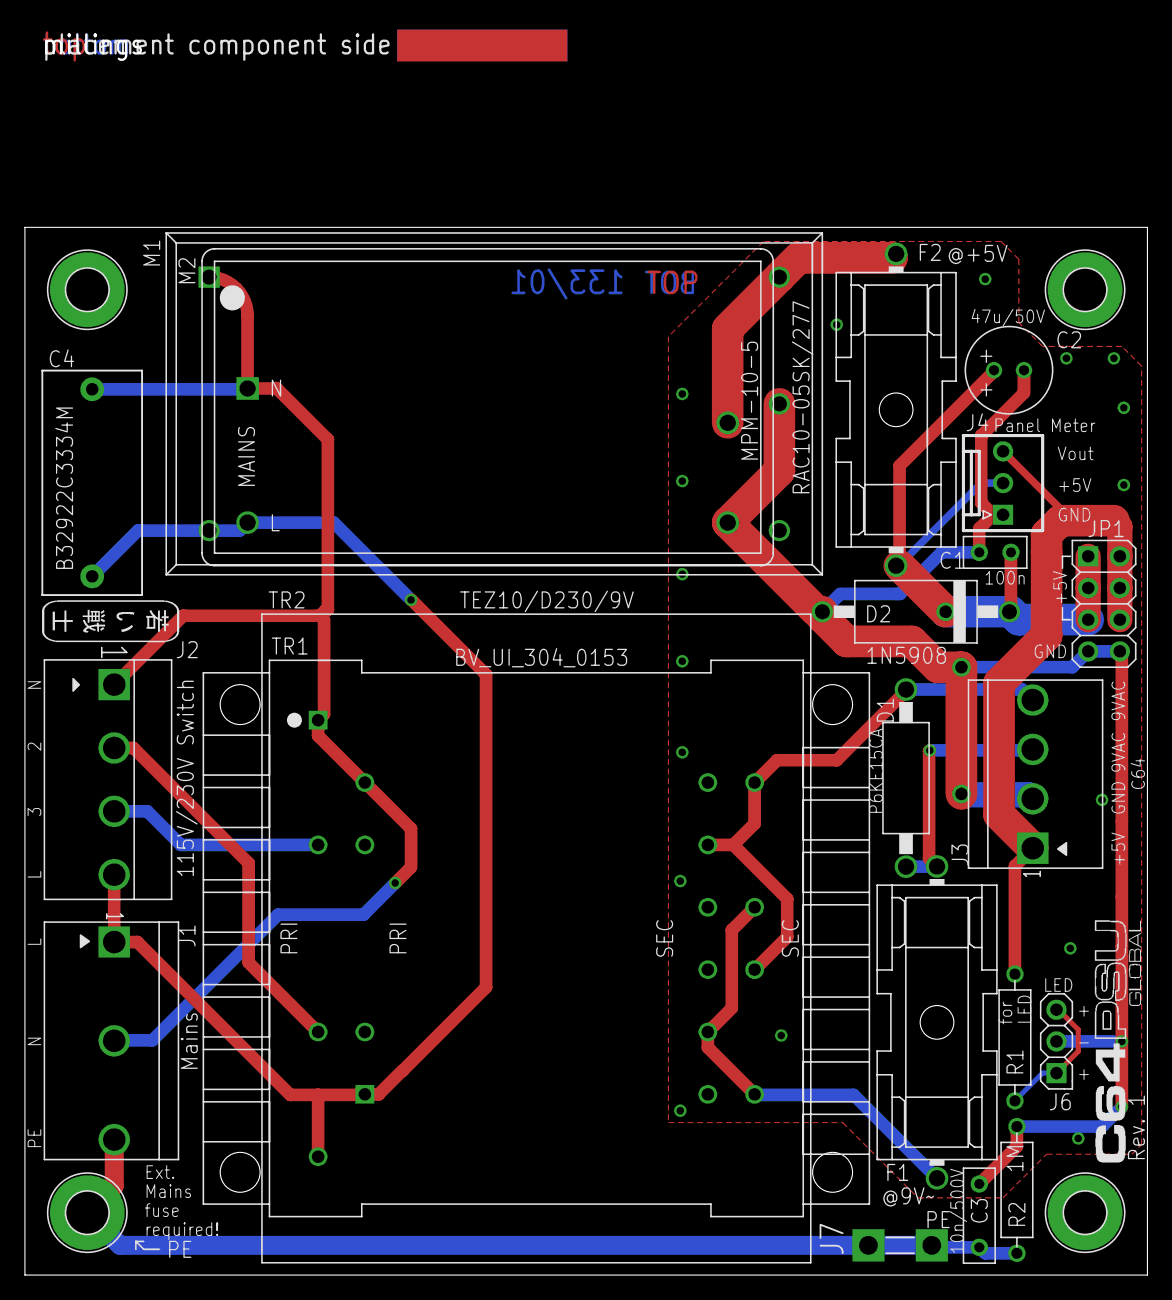
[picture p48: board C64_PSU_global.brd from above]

Board: 2 copper layers, 90.0 x 84.0 mm, 30 parts (1 on the bottom side), 13 nets.

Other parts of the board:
U$14: PCB-TITLE/
U$20: SVEN_TAG
U$22: C64_PSU_GLOBAL
U$23: 2LAYER

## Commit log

2020-01-16 Initial release
    [C64_PSU_230_115.brd, C64_PSU_230_115.dxf, C64_PSU_230_115.sch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]
2020-03-13 Case release
    [bottom_shell_230V_only.stl, psug_bottom_shell.stl, psug_bottom_shell_230V_only.stl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]
2020-04-12 Rev. 1 released
    [C64_PSU_230_115.brd, C64_PSU_230_115.dxf, C64_PSU_230_115.sch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]
2020-05-26 Corrected BOM and added price calculation
    [C64_PSU_Global_BoM_v1_0 calc.xlsx, C64_PSU_Global_BoM_v1_0.xlsx]
2020-08-10 Silk Screen Update
    [C64_PSU_global.brd, C64_PSU_global.sch]
2022-02-26 Gerbers removed
2022-02-27 Outdated gerbers removed
